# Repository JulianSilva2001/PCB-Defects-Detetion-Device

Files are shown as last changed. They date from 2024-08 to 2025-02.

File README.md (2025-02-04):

# PCB Defects Detection Device

This repository contains the code and resources for a PCB defects detection device. The project utilizes computer vision techniques and machine learning models to identify and classify defects in printed circuit boards (PCBs). 

## Overview

The PCB defects detection device is designed to automate the inspection process, ensuring high-quality standards in PCB manufacturing. The device employs a camera to capture images of PCBs and uses a trained model to detect various types of defects.

## Features

- *Defect Detection:* Identifies multiple PCB defects using a trained YOLOv8 model.
- *Component Placement Verification:* Compares PCB images to detect misaligned or missing components.

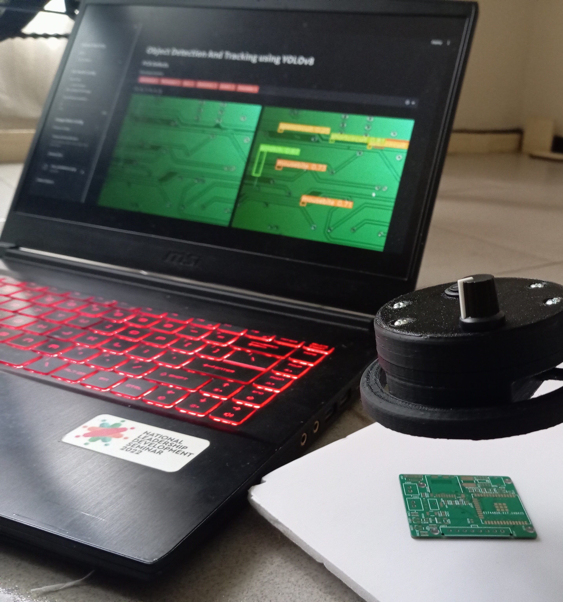
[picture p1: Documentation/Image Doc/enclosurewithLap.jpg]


- **Computer Vision**: The project uses computer vision to process and analyze images of PCBs. This involves techniques such as image enhancement, feature matching, image transformation,  feature extraction, and object detection.
- **Model Training**: A machine learning model is trained on a dataset of PCB images with labeled defects. The model learns to identify and classify defects based on patterns in the images.
- **PCB Schematic and Design**: The repository includes the PCB schematic and design files, providing a comprehensive guide to the hardware setup.
- **Enclosure Design**: Design files for the device enclosure are also included, ensuring a complete package for building the physical device.
- **Web App**: The code for the web application used to interact with the device is also available, allowing for real-time monitoring and analysis through a user-friendly interface.

## PCB and Schematic Design

### 🔩 Component Selection
The PCB inspection device consists of the following key modules:
1. **Microcontroller:** ESP-WROOM-32 (ESP32)
2. **Camera:** OV2460
3. **Lighting System:** High-brightness LED strip
4. **Power Supply:** Micro USB-powered regulated system

### 🔌 Microcontroller: ESP-WROOM-32
The ESP32S is chosen for its:
- **WiFi and Bluetooth Integration:** Enables high-speed image transmission (~6 Mbps).
- **Processing Power:** Dual-core Tensilica LX6 (240 MHz) for efficient image processing.
- **Memory:** 520 KB SRAM to support high-performance operations.

### 📷 Camera: OV5640
- **Resolution:** 5MP sensor 
- **Optical Features:** Low light sensitivity and high dynamic range for accurate PCB inspection.
- **Digital Video Port (DVP) Interface:** Ensures seamless integration with ESP32.
- **Power Requirements:** 2.8V core operation, 1.2V I/O.

### 🔋 Power Supply
- **Voltage Regulation:** Converts 5V USB input to required voltages.
- **Stable Power:** Voltage regulators ensure consistent performance.
- **Convenience:** USB-powered for easy deployment.

### 💡 Lighting System
- **LED Strip:** Provides uniform illumination for defect detection.
- **Adjustable Intensity:** Controlled via a potentiometer for adaptable lighting conditions.
- **Enhanced Versatility:** Ensures accurate inspection across diverse environments.

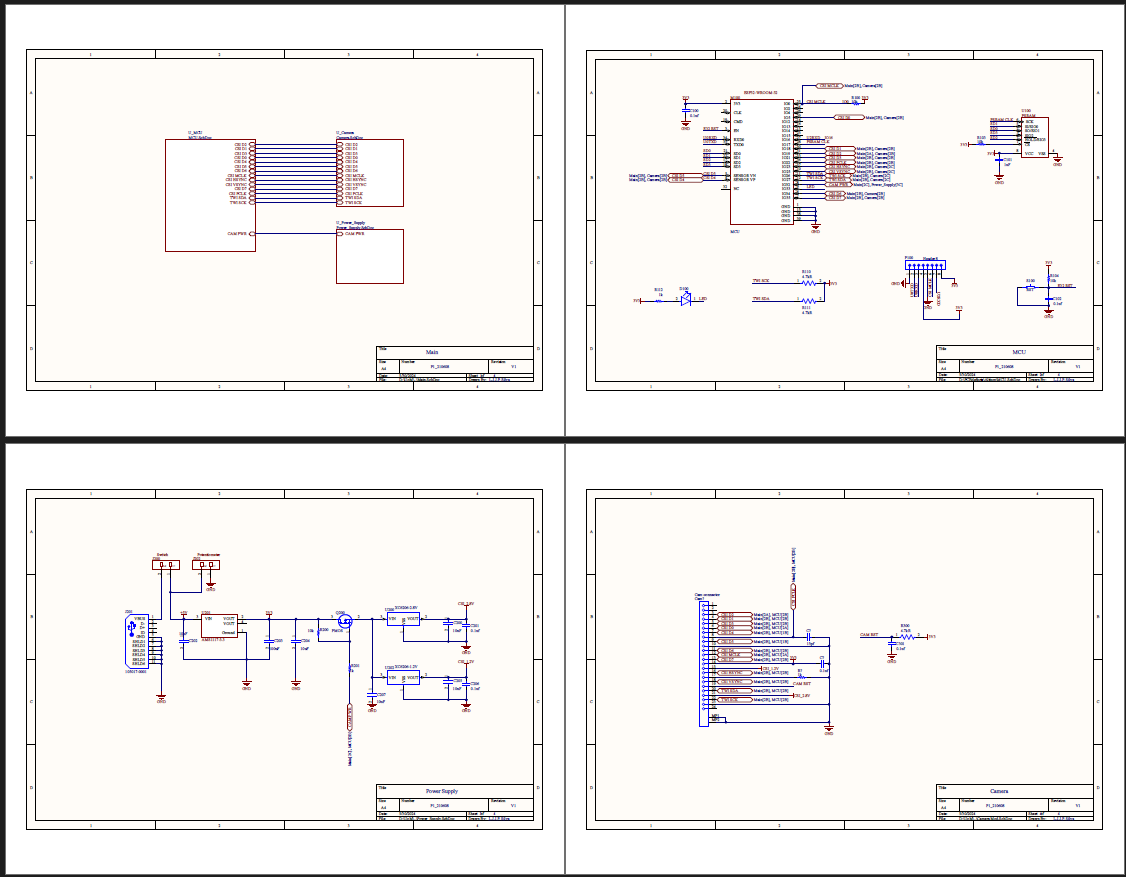
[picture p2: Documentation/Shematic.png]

*Figure 1: Schematic Diagram*

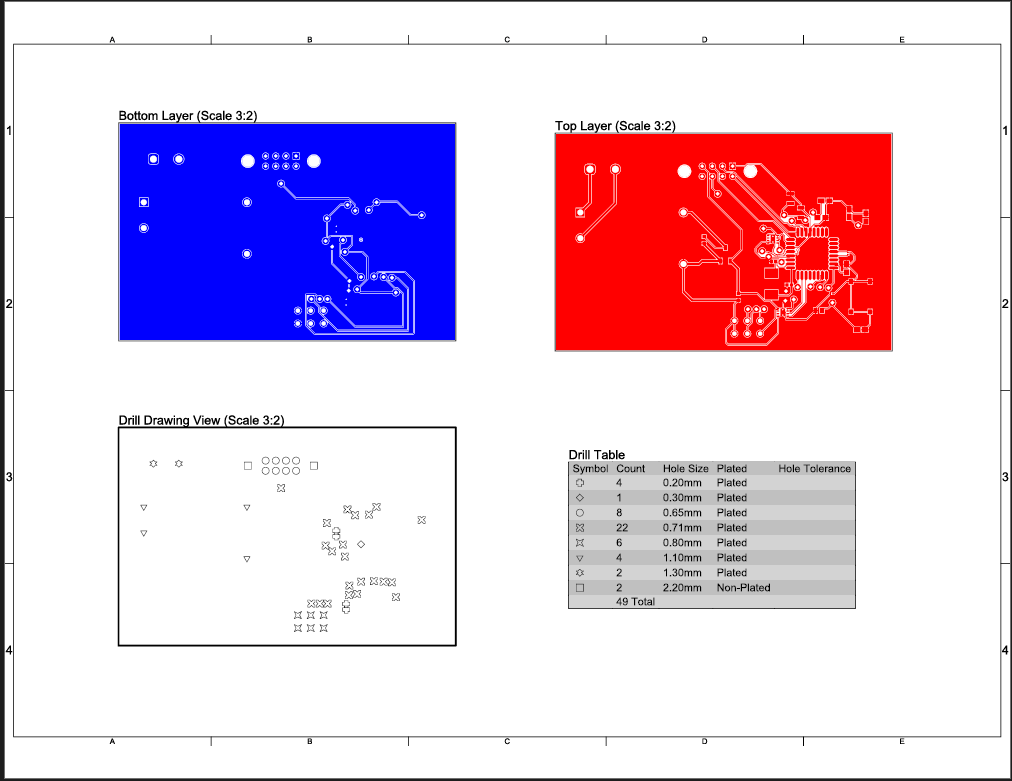
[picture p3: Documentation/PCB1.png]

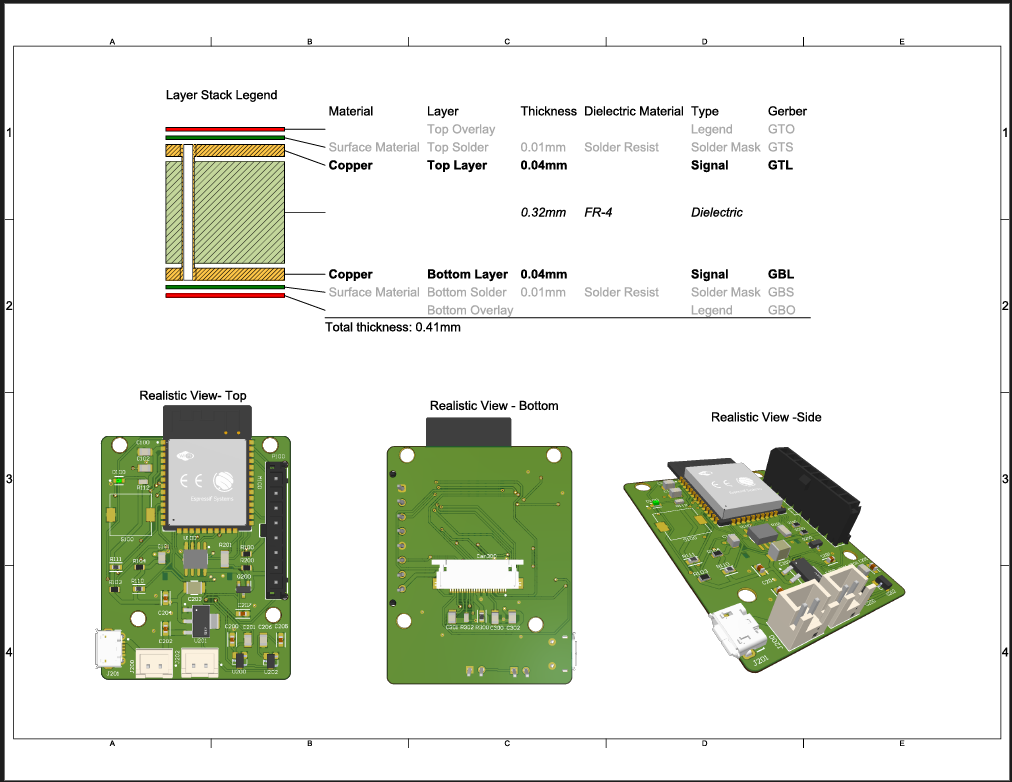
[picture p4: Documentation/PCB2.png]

*Figure 2: PCB Design*

## Enclosure Design 

### 🏗 Key Considerations
The enclosure was designed to optimize functionality, ease of use, and performance:

1. **Mounting for Camera and PCB**
   - Dedicated mounting points secure the camera and PCB for stable inspection.
   
2. **Acrylic Flat Surface**
   - Provides a clear, stable platform for precise PCB inspection.

3. **Adjustable Camera Height**
   - An aluminum bar allows users to set the optimal distance for capturing detailed images.

4. **Ring of Light**
   - Ensures uniform illumination, eliminating shadows for accurate defect detection.

5. **On/Off Button**
   - Controls the power supply, enhancing convenience and safety.

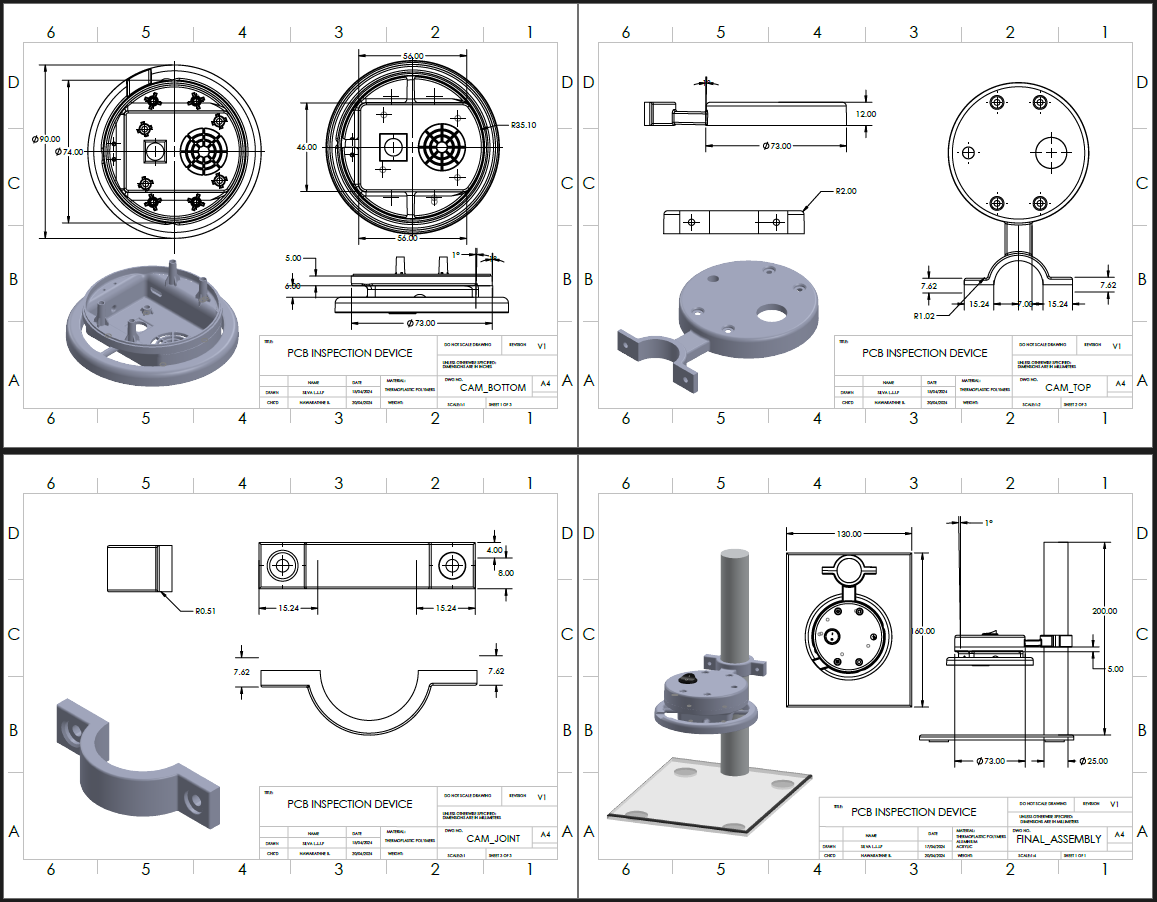
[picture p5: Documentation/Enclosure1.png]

*Figure 3: Enclosure V1*

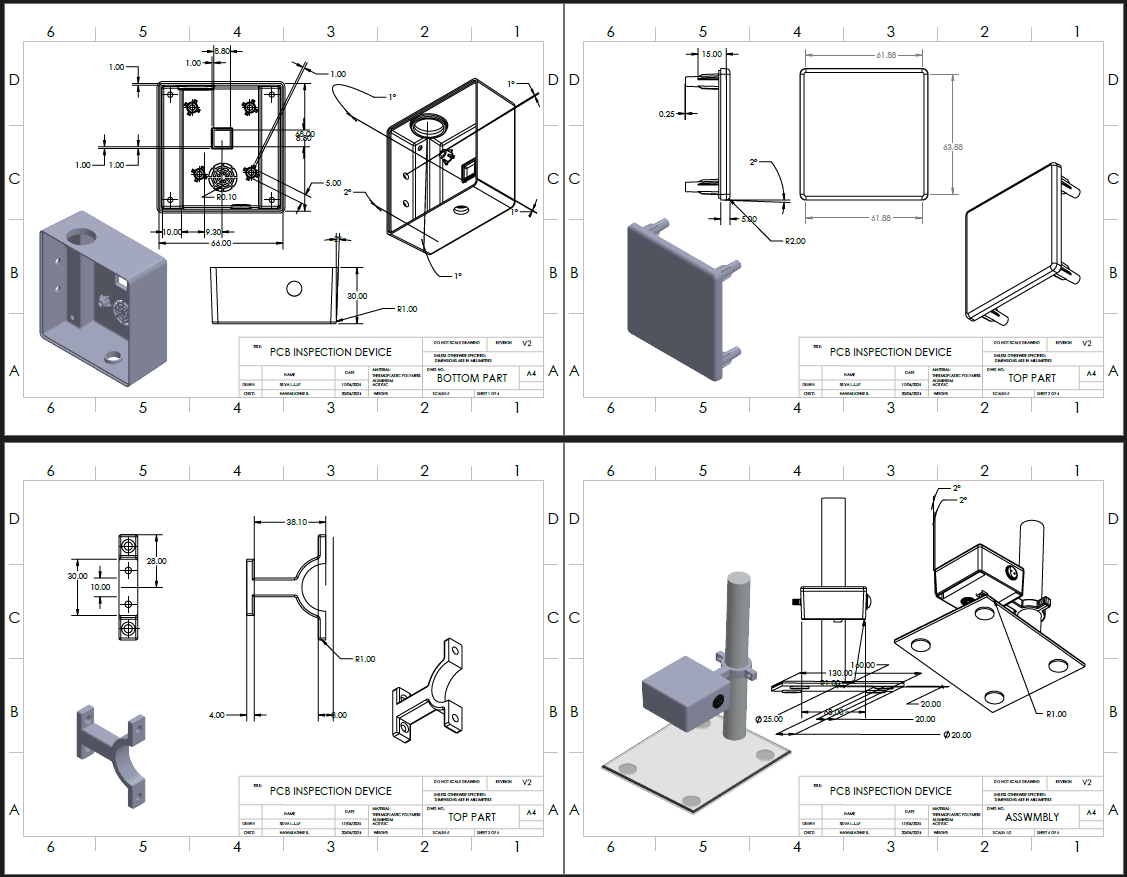
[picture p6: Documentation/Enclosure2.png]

*Figure 4: Enclosure V2*

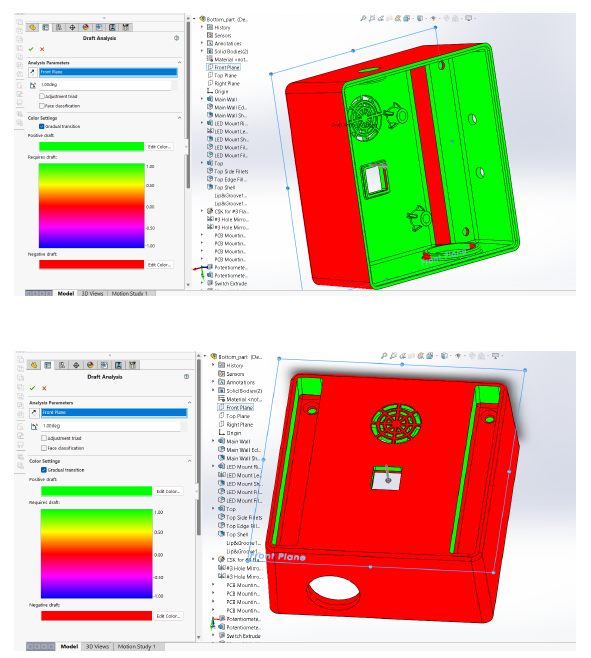
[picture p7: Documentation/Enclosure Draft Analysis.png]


*Figure 5: Draft Analysis*

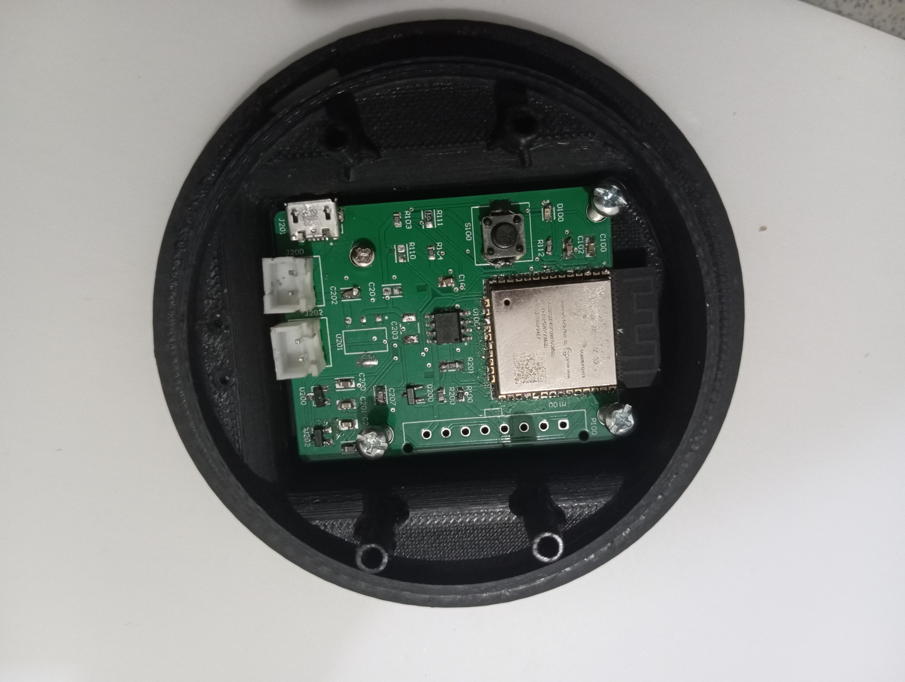
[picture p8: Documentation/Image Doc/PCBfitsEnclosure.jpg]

*Figure 6: How the PCB fits the enclosure*

## 🌐 Building the Web Application

### 📂 Application Structure
The web app offers real-time PCB defect detection through a live camera feed or image uploads.

### 🏠 Home Page
Displays a **welcome message** and describes the types of defects detected:
- Missing Hole
- Mouse Bite
- Open Circuit
- Short Circuit
- Spur
- Spurious Copper

Users can choose between **Live Inspection** or **Upload Images**.

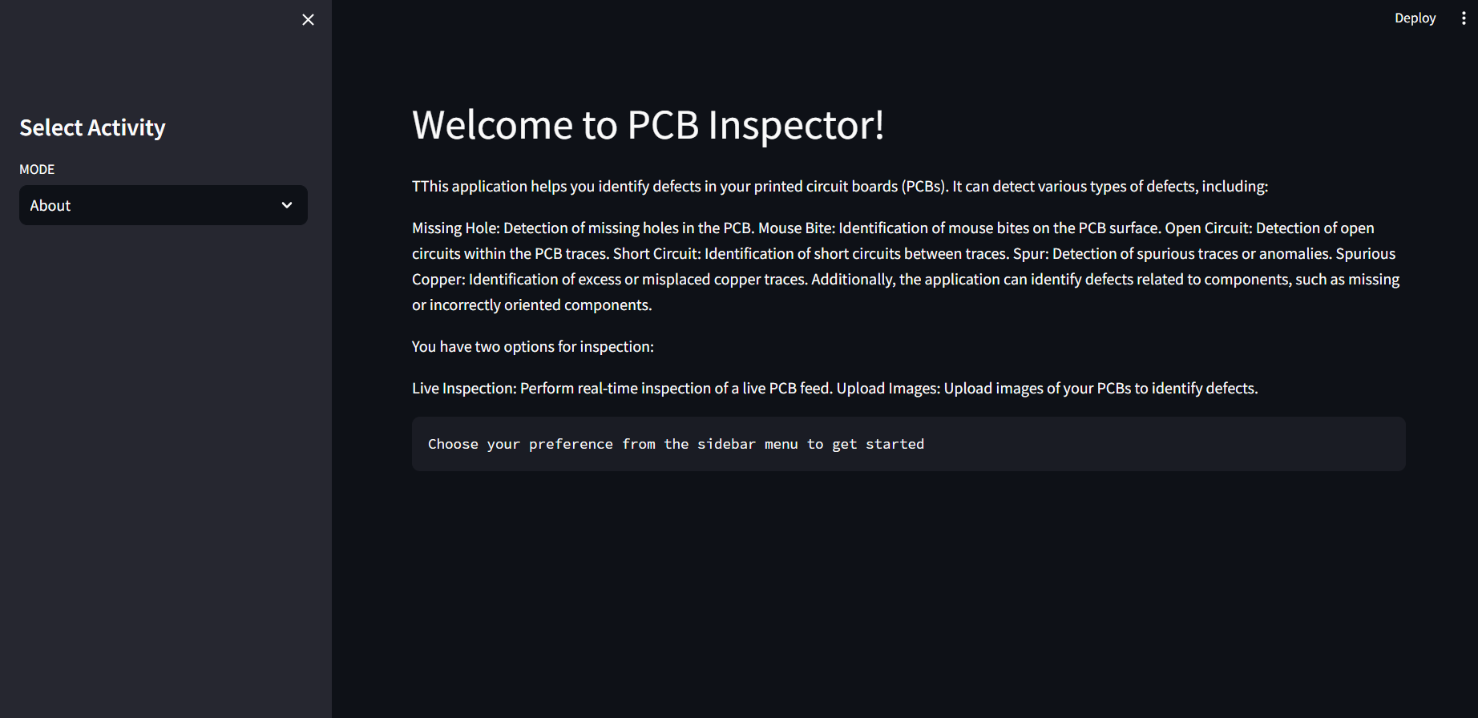
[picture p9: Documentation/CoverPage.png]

*Figure 7: Cover Page*

### 📑 Sidebar Menu
Provides navigation options:
- **About**
- **PCB Defects**
- **Component Defects**

### 🖼 PCB Defects Page
#### ⚙ Model Configuration
Users can:
- Select **Live Camera** or **Upload PCB Image**.
- Adjust model confidence using a slider.

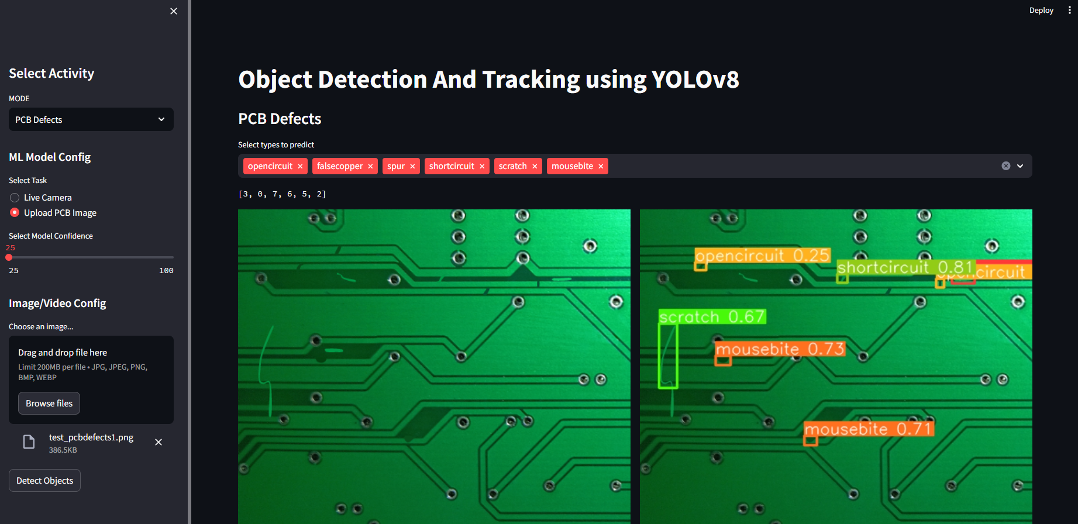
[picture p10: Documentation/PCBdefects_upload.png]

*Figure 8: PCB defects Detection Page* 

#### 🎥 Live Camera Mode
- Captures real-time images.
- Detects defects using the YOLO model.
- Highlights defects on the processed image.

#### 📤 Upload PCB Image Mode
- Users upload PCB images in various formats.
- The app processes and highlights detected defects.

### 🔩 Component Defects Page
Similar to PCB defects detection, but focuses on **component placement**.

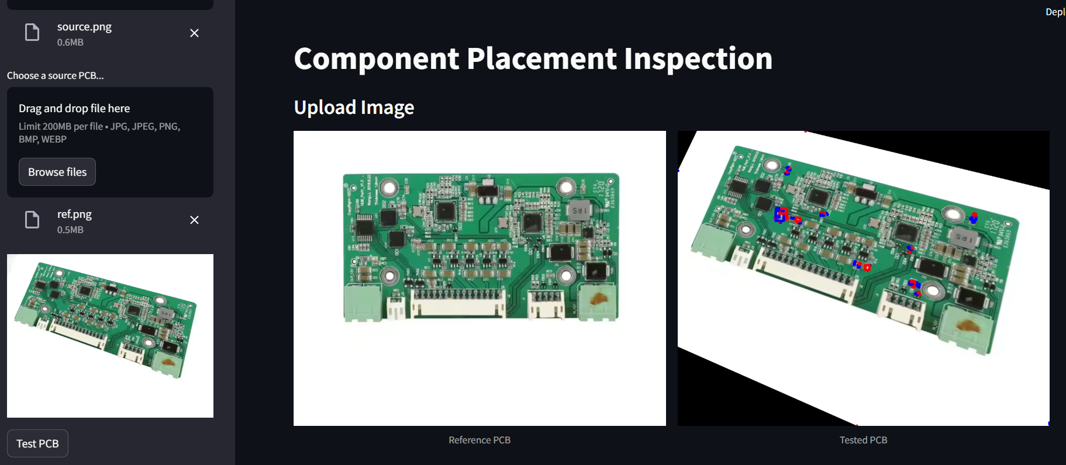
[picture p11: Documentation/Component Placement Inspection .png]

*Figure 8: Component Placement Inspection Page* 

#### 🎥 Live Camera Mode
- Captures a reference image.
- Compares it with live images to detect misalignments.

#### 📤 Upload PCB Image Mode
- Users upload a **reference** and **source image**.
- The app highlights component defects based on differences.

## Getting Started

1. **Clone the Repository**: 
    ```bash
    git clone https://github.com/yourusername/pcb-defects-detection-device.git
    ```

2. **Running the Device**: Follow the setup instructions in the documentation to assemble the hardware and run the device.

🤝 Contributing

Contributions are welcome! Feel free to submit issues or pull requests.

## Documentation

Detailed documentation, including setup instructions and usage guidelines, can be found in the [project document](https://github.com/JulianSilva2001/PCB-Defects-Detetion-Device/blob/main/Documentation/PCB_Defects_Detection_Documentation%20(7).pdf).

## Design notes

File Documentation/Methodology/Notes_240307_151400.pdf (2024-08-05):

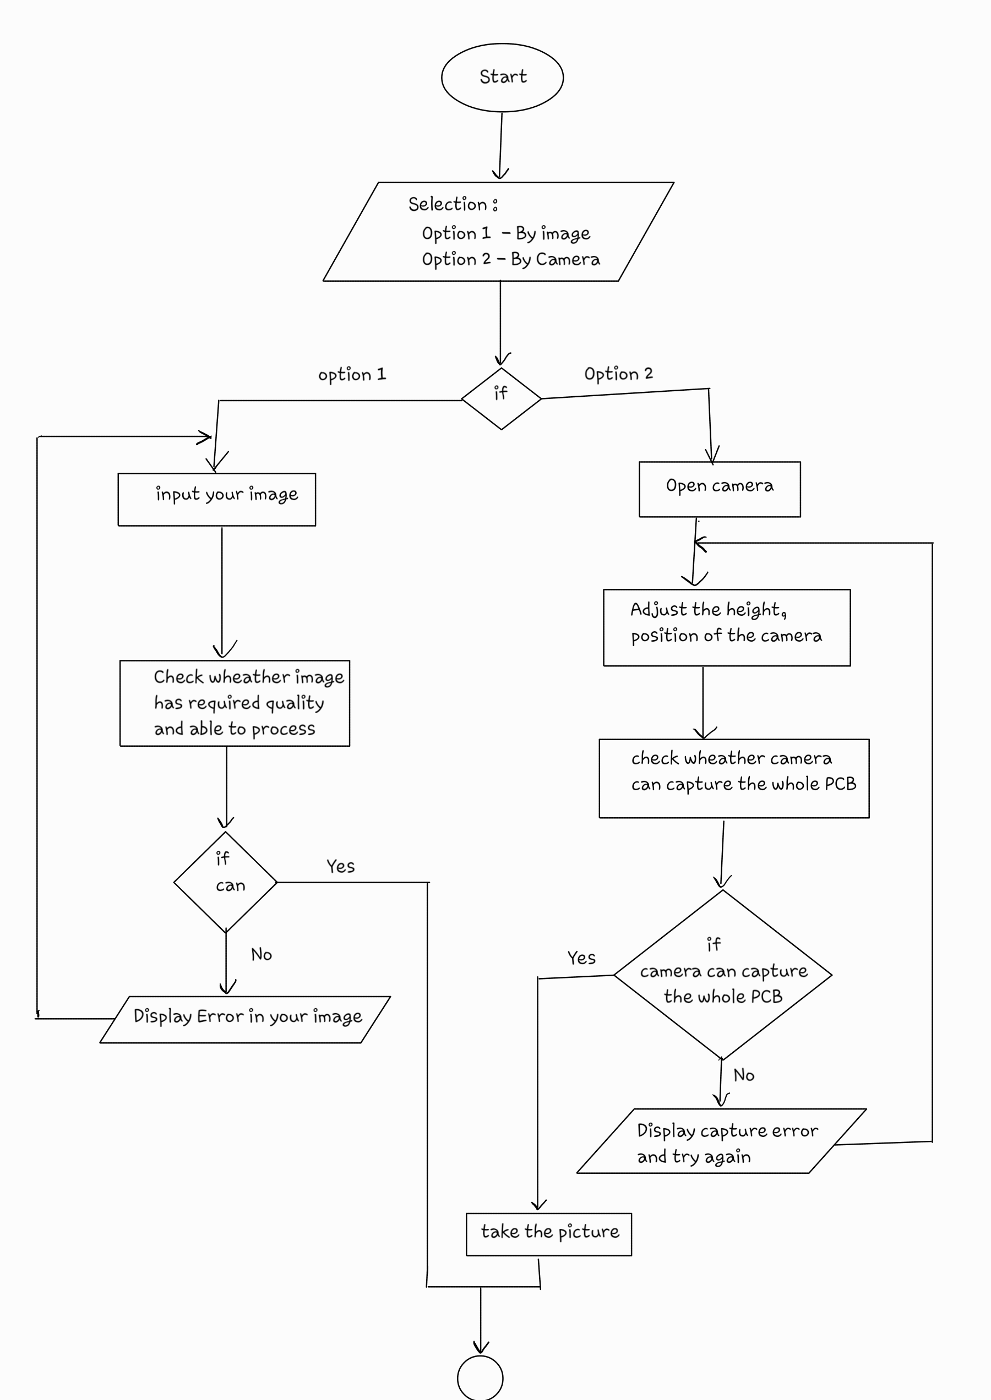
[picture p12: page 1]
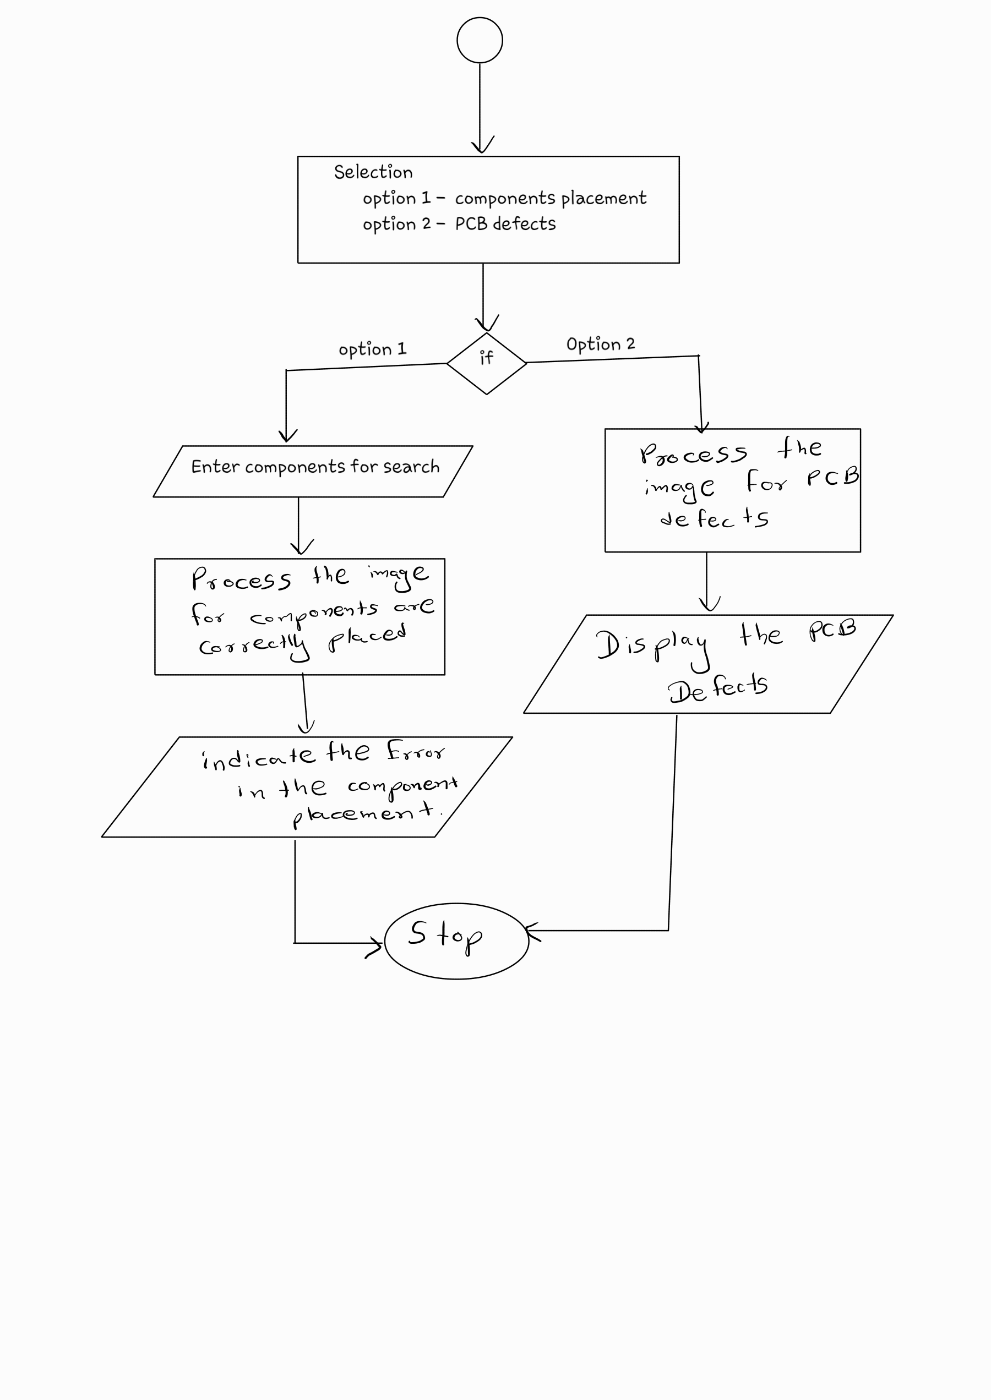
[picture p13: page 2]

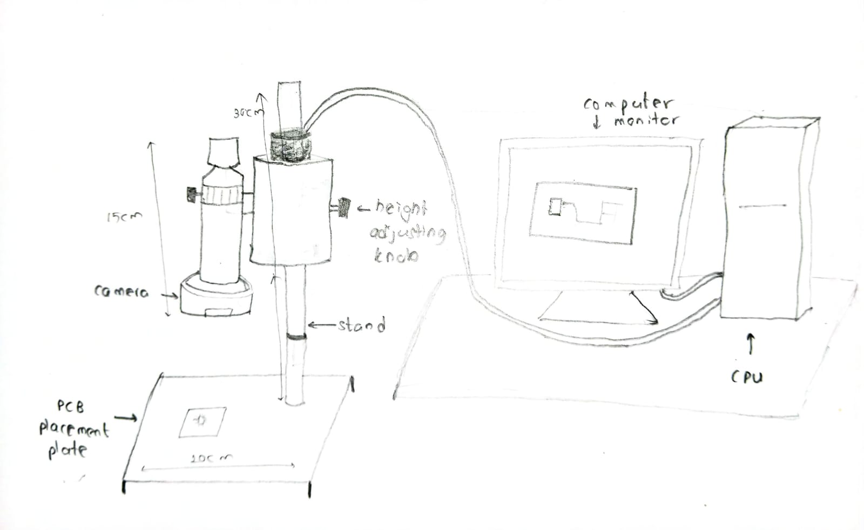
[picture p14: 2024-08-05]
Documentation/Methodology/Conceptual Design/CD_Comp.jpg

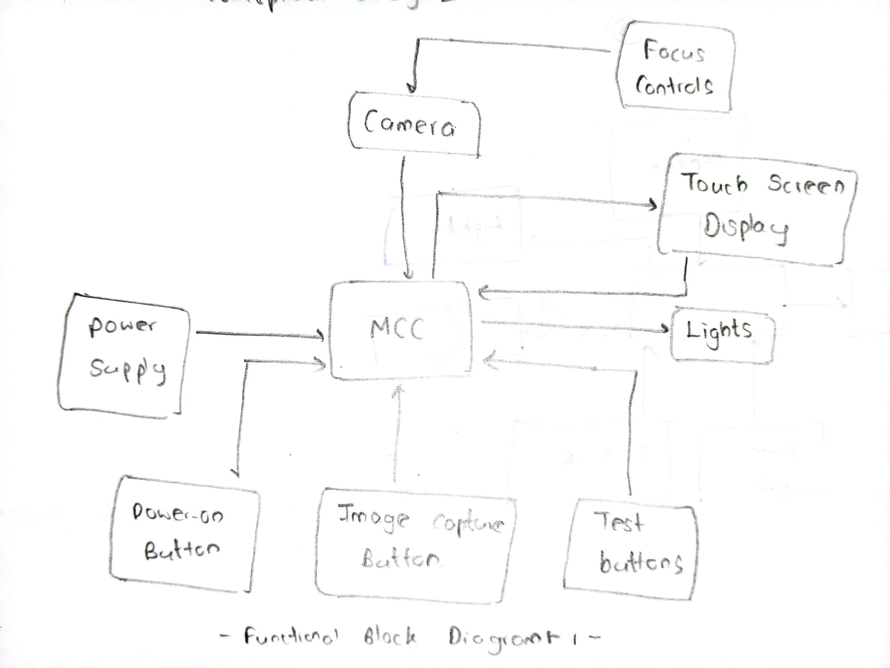
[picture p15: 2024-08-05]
Documentation/Methodology/Conceptual Design/FD_display.jpg

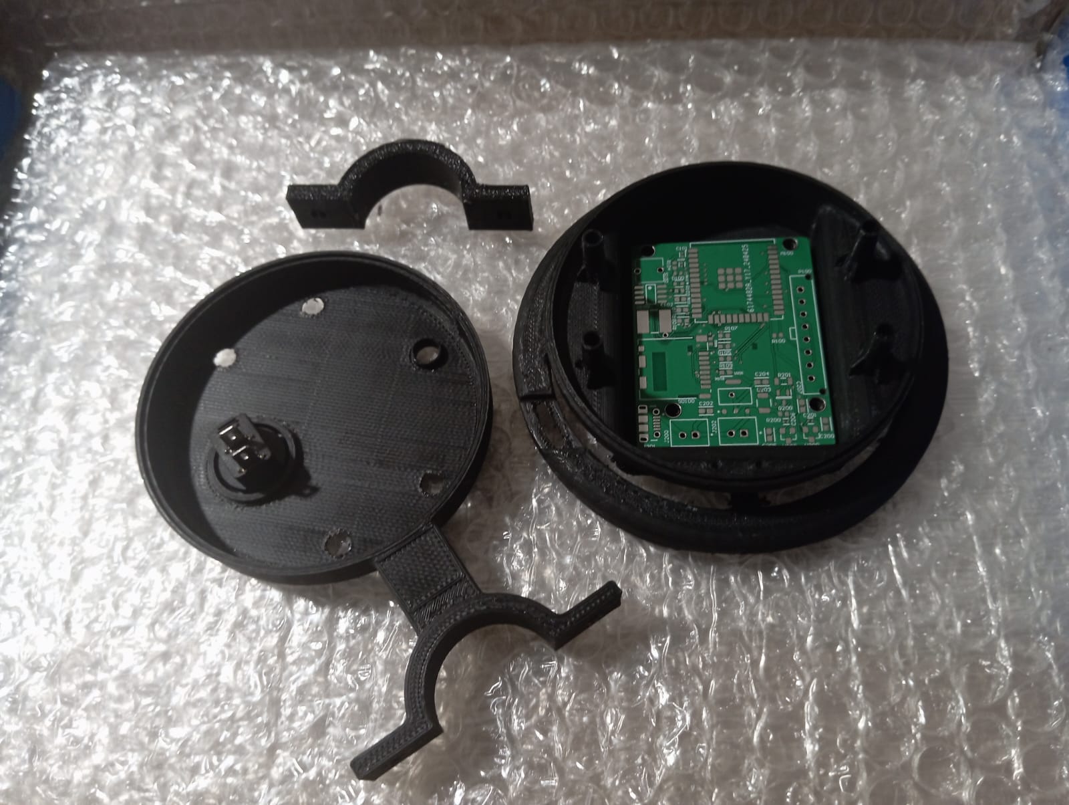
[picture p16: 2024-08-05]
Documentation/Conceptual Design/Enclosure/Enclosure Design A3.jpg

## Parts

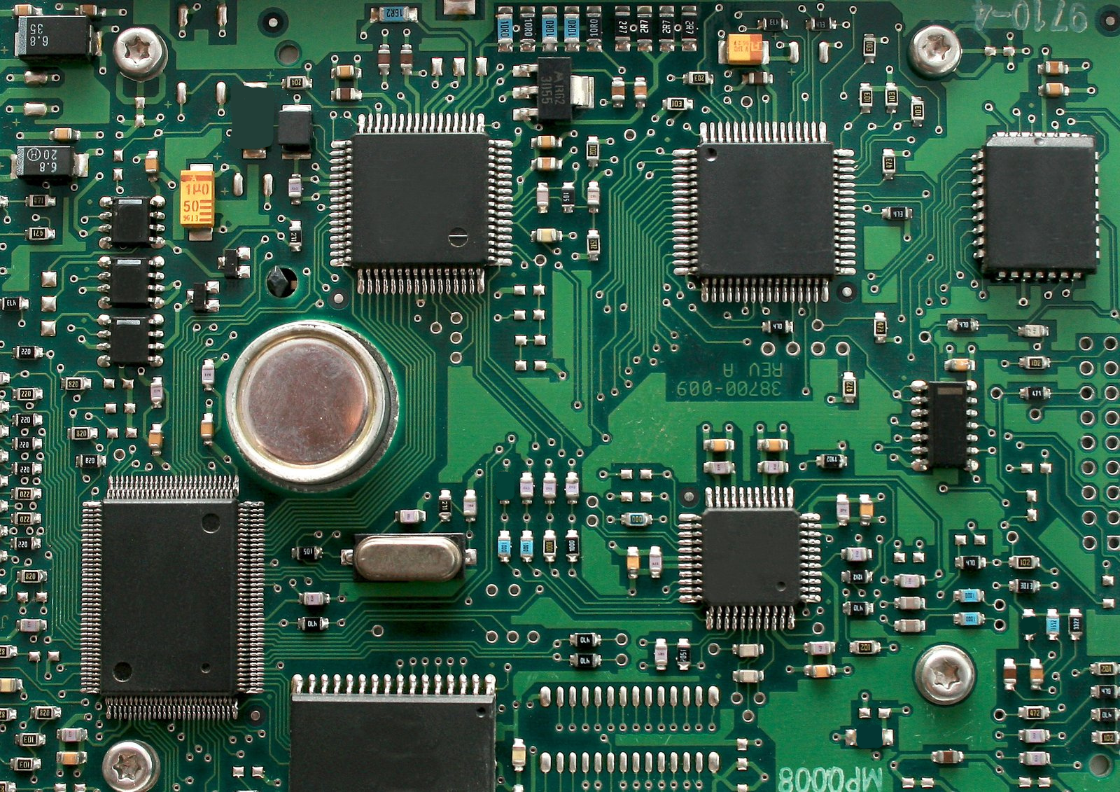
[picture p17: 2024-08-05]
code/Test Images/Component Deffects/PCB_Ctest1_D.png

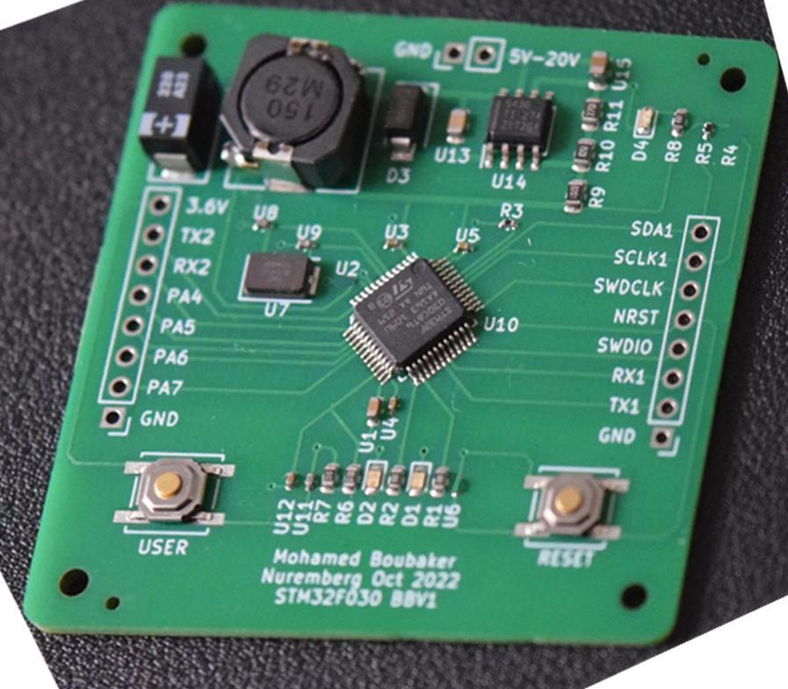
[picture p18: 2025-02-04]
code/Test Images/Component Deffects/anamoly_2/warped.png

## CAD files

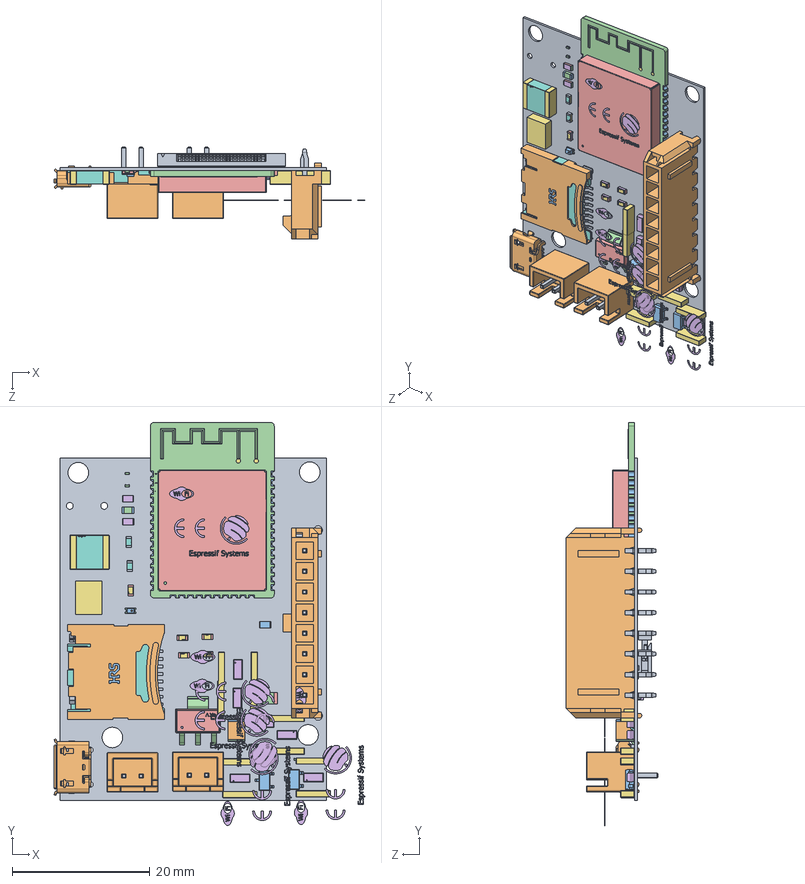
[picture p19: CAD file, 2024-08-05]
Altium/PCB_F.step.SLDASM
45.2 x 58.6 x 13.3 mm
1.step
2.step
3.step
4.step
Lite-On Logo Adjustable.step
5.step
6.step
1-1.step x 2
B2B-XH-A.step x 2
JST Logo adjustable.step x 2
Mid_Body.step x 2
Mark.step x 2
1-2.step x 3
2-3.step x 3
3-4.step x 3
Panasonic Logo.step x 3
Extruded.step x 2
Extruded-5.step
Pieza60.step x 5
Pieza63.step x 5
Pieza64.step x 5
Pieza65.step x 5
Mid_Body-7.step x 2
Mark-8.step x 2
Cap_Murata_GRM155R71C104KA88D_eec.step x 6
Extruded-9.step
Extruded-10.step x 2
Terminals.step x 6
Center.step
Murata.step
6605298272.step x 2
1-12.step
Notch 2.step
Extruded-13.step
DM3CS-SF.step
Pieza12.step
Pieza13.step
Pieza14.step
Extruded-14.step
Extruded-15.step x 2
Body.step x 6
PinsArrayL.step
FilletPinR.step
6620xx11122_PIN.step x 8
66200811122-16.step
2-18.step
3-19.step
ESP32-WROOM-32D.step
Logo.step x 6
10.step
11.step
Cap_Murata_GRM32ER60J107ME20L_eec.step
Cap_Murata_GRM32ER60J107ME20L_eec-20.step
Cap_Murata_GRM32ER60J107ME20L_eec-21.step

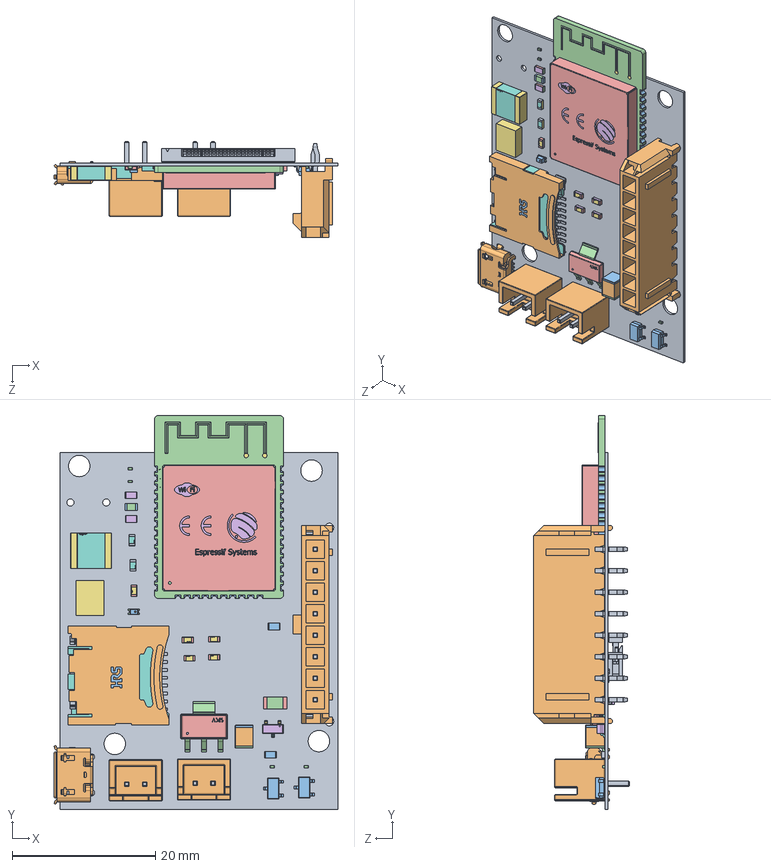
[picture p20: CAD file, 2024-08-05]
Altium/PCB1.step.SLDASM
39.6 x 54.9 x 13.3 mm
1.step
2.step
3.step
4.step
Lite-On Logo Adjustable.step
5.step
6.step
1-1.step x 2
B2B-XH-A.step x 2
JST Logo adjustable.step x 2
Mid_Body.step x 2
Mark.step x 2
1-2.step x 3
2-3.step x 3
3-4.step x 3
Panasonic Logo.step x 3
Extruded.step x 2
Extruded-5.step
Pieza60.step x 5
Pieza63.step x 5
Pieza64.step x 5
Pieza65.step x 5
Mid_Body-7.step x 2
Mark-8.step x 2
Cap_Murata_GRM155R71C104KA88D_eec.step x 6
Extruded-9.step
Extruded-10.step x 2
Terminals.step
Center.step
Murata.step
6606193888.step x 2
1-12.step
Notch 2.step
Extruded-13.step
DM3CS-SF.step
Pieza12.step
Pieza13.step
Pieza14.step
Extruded-14.step
Extruded-15.step x 2
Body.step
PinsArrayL.step
FilletPinR.step
6620xx11122_PIN.step x 8
66200811122-16.step
2-18.step
3-19.step
ESP32-WROOM-32D.step
Logo.step
10.step
11.step
Cap_Murata_GRM32ER60J107ME20L_eec.step
Cap_Murata_GRM32ER60J107ME20L_eec-20.step
Cap_Murata_GRM32ER60J107ME20L_eec-21.step

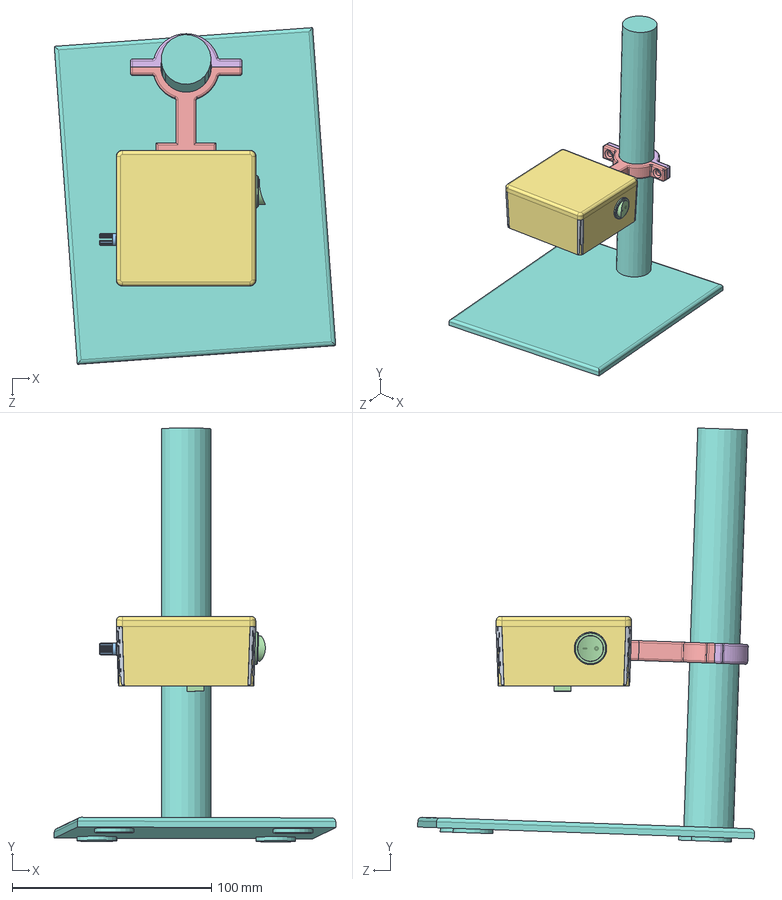
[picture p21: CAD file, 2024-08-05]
Solidworks V2/AssemV2.SLDASM
141.2 x 207.7 x 169.0 mm
Bottom_part
PCB1.step
POT10K.step
Button v5.step
Joint
Joint_part
Bottom
base
User Library-LI-OV5640-MIPI-AF_Designator1
User Library-LI-OV5640-MIPI-AF_942681200
User Library-LI-OV5640-MIPI-AF_942681064
User Library-LI-OV5640-MIPI-AF_942680928
User Library-LI-OV5640-MIPI-AF_942680792
User Library-LI-OV5640-MIPI-AF_942680656
User Library-LI-OV5640-MIPI-AF_942676304

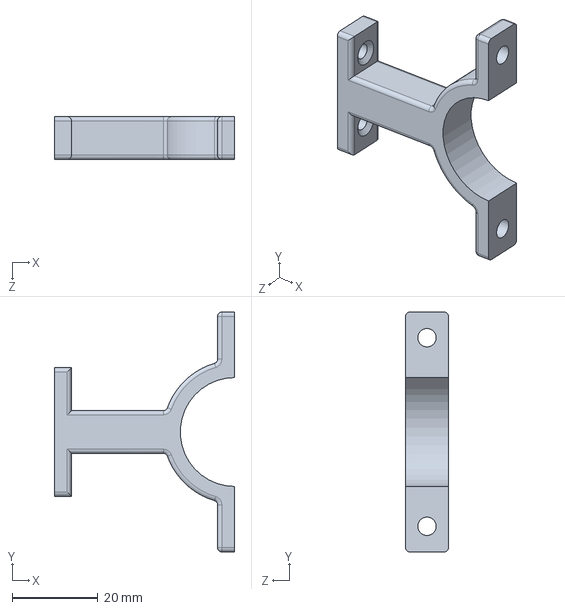
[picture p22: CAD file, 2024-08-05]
Solidworks V2/Joint.SLDPRT
42.1 x 56.0 x 10.0 mm

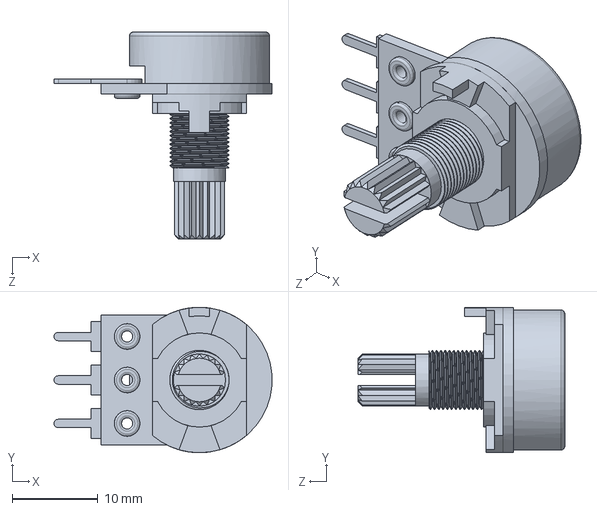
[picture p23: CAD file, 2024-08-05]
Solidworks V2/PCB/POT10K.step.SLDPRT
25.5 x 17.0 x 24.2 mm

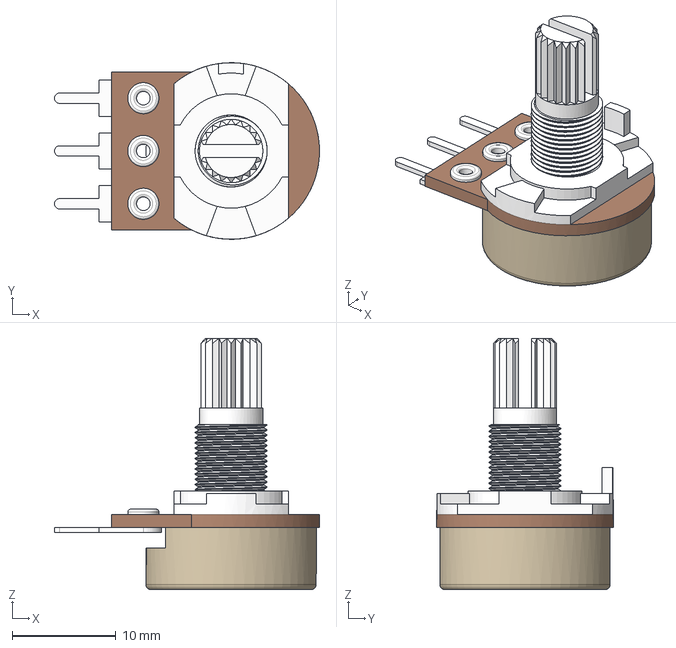
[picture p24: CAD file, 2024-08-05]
Solidworks V2/PCB/potentiometer-10k-2.snapshot.2 (1)/POT10K.step
25.5 x 17.0 x 24.2 mm

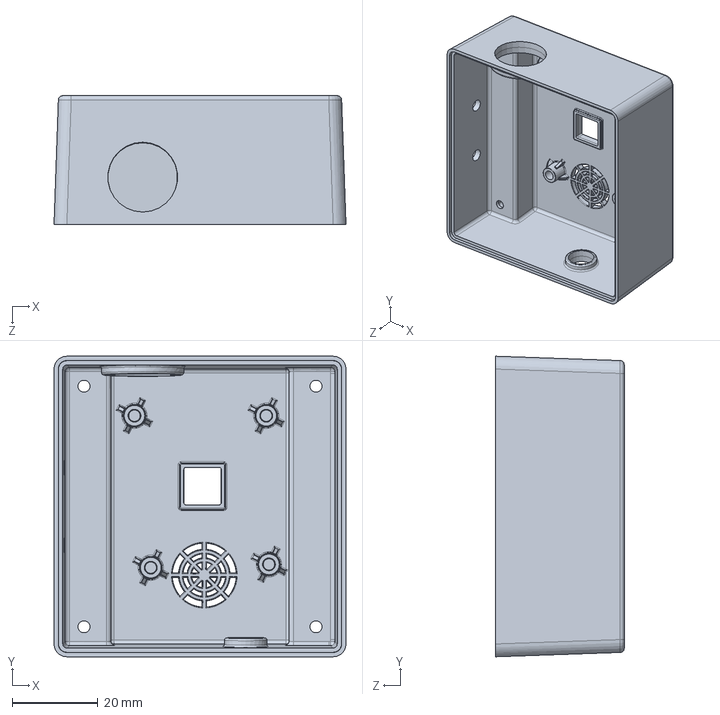
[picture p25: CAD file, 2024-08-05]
Solidworks V2/Bottom_part.SLDPRT
68.1 x 70.1 x 30.0 mm

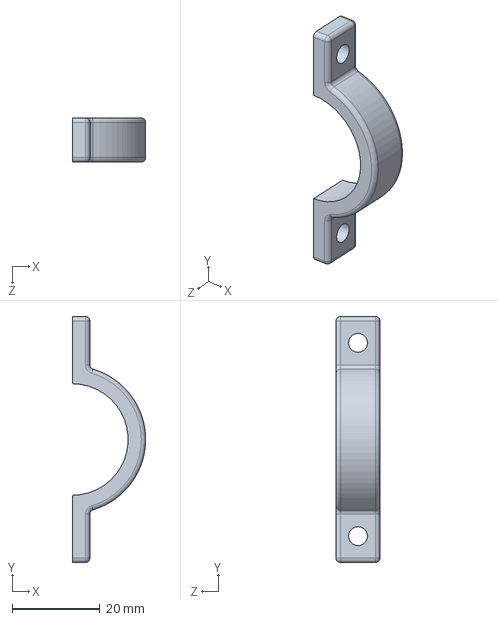
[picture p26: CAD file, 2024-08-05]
Solidworks V2/Joint_part.SLDPRT
16.7 x 56.0 x 10.0 mm

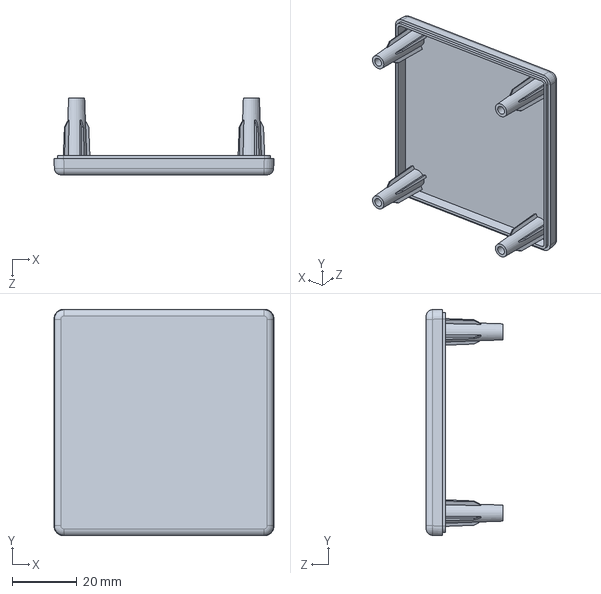
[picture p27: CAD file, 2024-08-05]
Solidworks V2/Bottom.SLDPRT
68.1 x 70.1 x 23.7 mm

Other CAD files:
Solidworks V2/PCB/potentiometer-10k-2.snapshot.2 (1)/POT10K.f3d
Solidworks V2/PCB/potentiometer-10k-2.snapshot.2 (1)/POT10K.obj

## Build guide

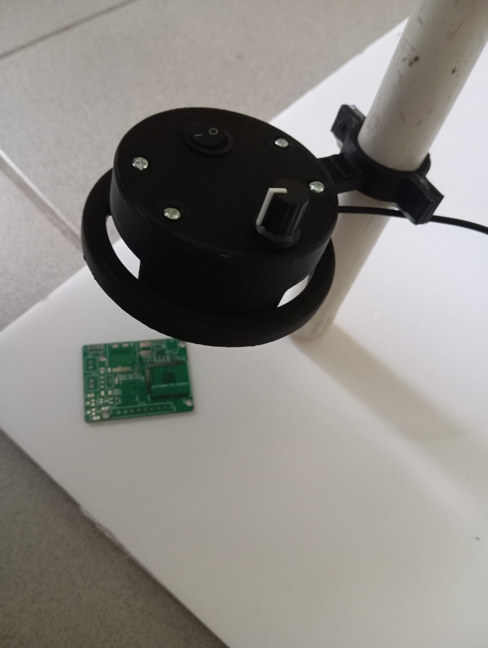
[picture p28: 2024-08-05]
Documentation/Image Doc/AssembledEnclosure2.jpg

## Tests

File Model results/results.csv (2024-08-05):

epoch | train/box_loss | train/cls_loss | train/dfl_loss | metrics/precision(B) | metrics/recall(B) | metrics/mAP50(B) | metrics/mAP50-95(B) | val/box_loss | val/cls_loss | val/dfl_loss | lr/pg0 | lr/pg1 | lr/pg2
1 | 2.5854 | 3.2818 | 1.4706 | 0.55606 | 0.61447 | 0.50088 | 0.19827 | 2.0494 | 7.168 | 1.1111 | 0.00027717 | 0.00027717 | 0.00027717
2 | 2.2103 | 1.6528 | 1.2155 | 0.70733 | 0.64771 | 0.66522 | 0.27632 | 1.9371 | 1.3186 | 1.0629 | 0.00052737 | 0.00052737 | 0.00052737
3 | 2.1476 | 1.5325 | 1.1813 | 0.75465 | 0.73706 | 0.75189 | 0.3144 | 1.9139 | 1.2722 | 1.0606 | 0.00075008 | 0.00075008 | 0.00075008
4 | 2.0644 | 1.4209 | 1.1518 | 0.75439 | 0.73968 | 0.76909 | 0.34063 | 1.8497 | 1.1182 | 1.0348 | 0.0007093 | 0.0007093 | 0.0007093
5 | 2.0046 | 1.3218 | 1.122 | 0.79086 | 0.77871 | 0.80208 | 0.3538 | 1.828 | 1.0678 | 1.0296 | 0.00066807 | 0.00066807 | 0.00066807
6 | 1.9478 | 1.2496 | 1.1023 | 0.81205 | 0.81001 | 0.82711 | 0.37972 | 1.7286 | 0.98288 | 0.99394 | 0.00062683 | 0.00062683 | 0.00062683
7 | 1.8992 | 1.1829 | 1.0803 | 0.82555 | 0.82302 | 0.84485 | 0.39776 | 1.702 | 0.92843 | 0.98793 | 0.0005856 | 0.0005856 | 0.0005856
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

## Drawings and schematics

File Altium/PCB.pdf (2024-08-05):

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
CSI D2
CSI D1
CSI D3
CSI D0
CSI D4
CSI D5
CSI D6
CSI MCLK
CSI HSYNC
CSI VSYNC
CSI D7
CSI PCLK
TWI SDA
TWI SCK

U_Camera
Camera.SchDoc

CAM PWR

U_Power_Supply
Power_Supply.SchDoc

CSI D5

CSI D4

CSI D1

CSI D2

CSI D3

CSI PCLK

CSI HSYNC
CSI VSYNC
CSI D7

CSI D6

CAM PWR

CSI MCLK

CSI D0

TWI SDA
TWI SCK

U_MCU
MCU.SchDoc

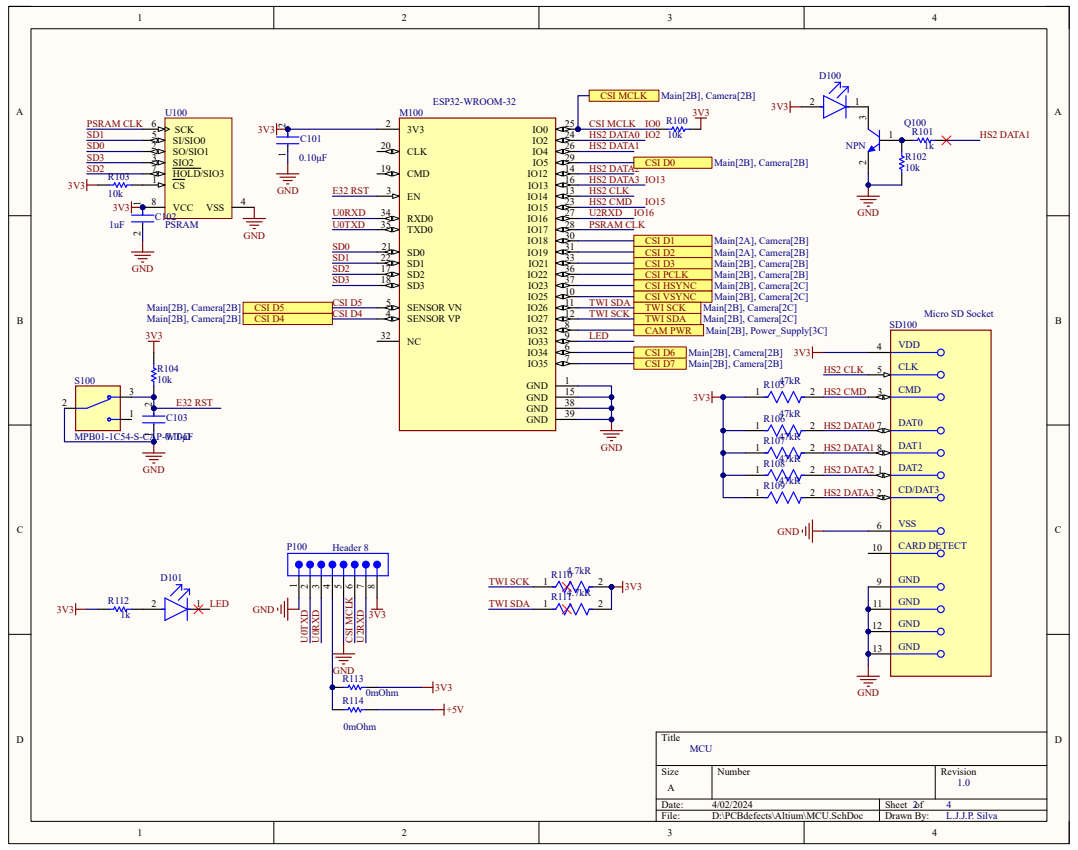
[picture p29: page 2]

# GND⁰¹ ⁰¹ 02 02 03 03 04 04

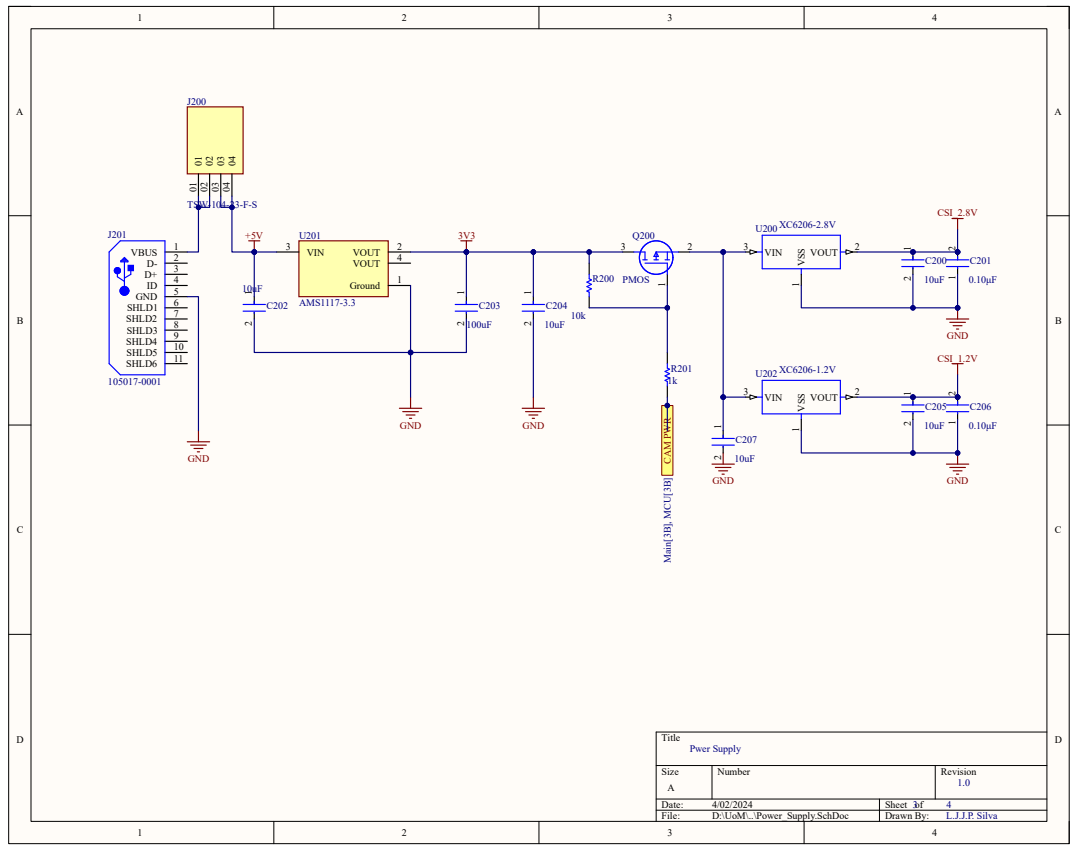
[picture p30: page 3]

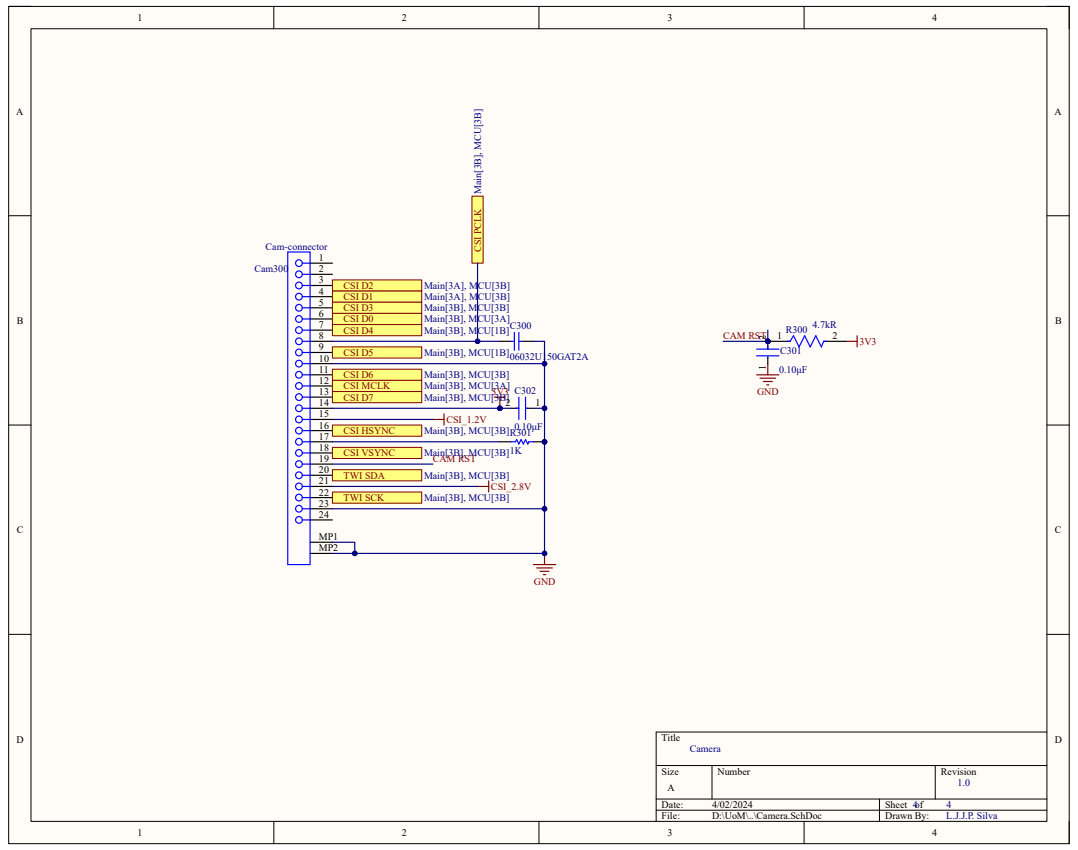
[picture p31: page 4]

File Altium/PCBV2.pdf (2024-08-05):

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
CSI D2
CSI D1
CSI D3
CSI D0
CSI D4
CSI D5
CSI D6
CSI MCLK
CSI HSYNC
CSI VSYNC
CSI D7
CSI PCLK
TWI SDA
TWI SCK

U_Camera
Camera.SchDoc

CAM PWR

U_Power_Supply
Power_Supply.SchDoc

CSI D5

CSI D4

CSI D1

CSI D2

CSI D3

CSI PCLK

CSI HSYNC
CSI VSYNC
CSI D7

CSI D6

CAM PWR

CSI MCLK

CSI D0

TWI SDA
TWI SCK

U_MCU
MCU.SchDoc

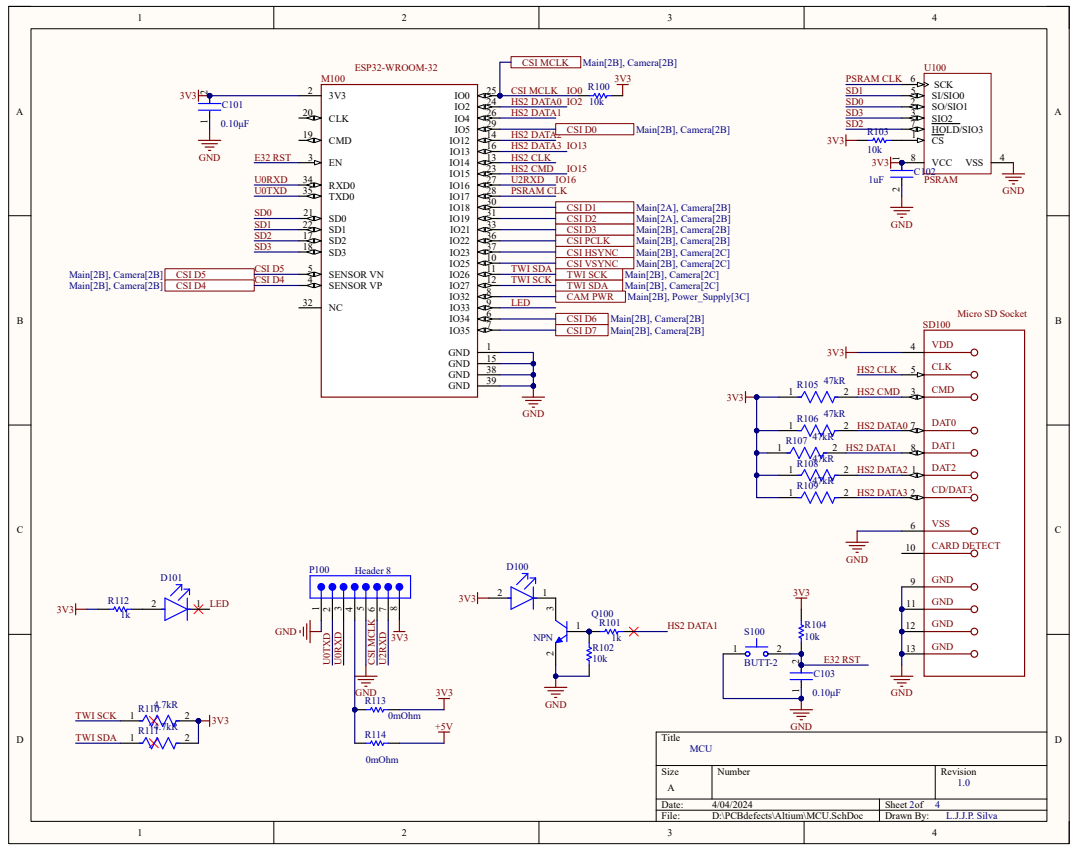
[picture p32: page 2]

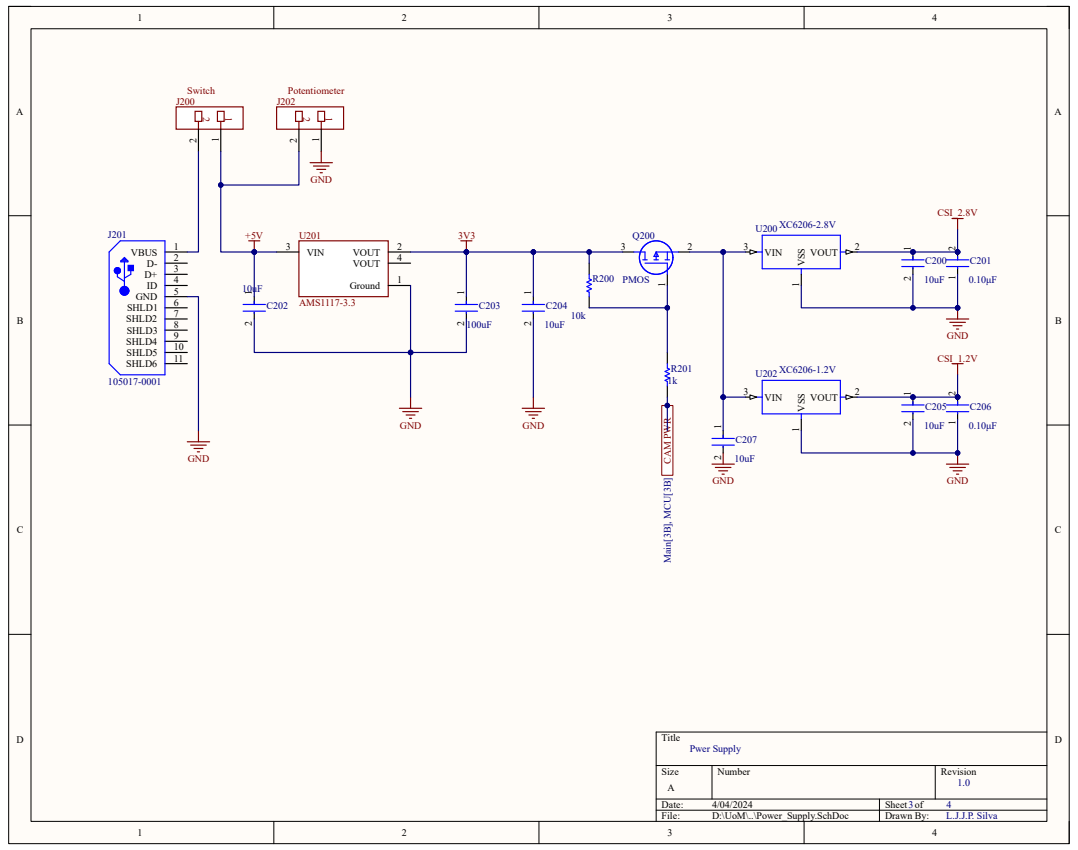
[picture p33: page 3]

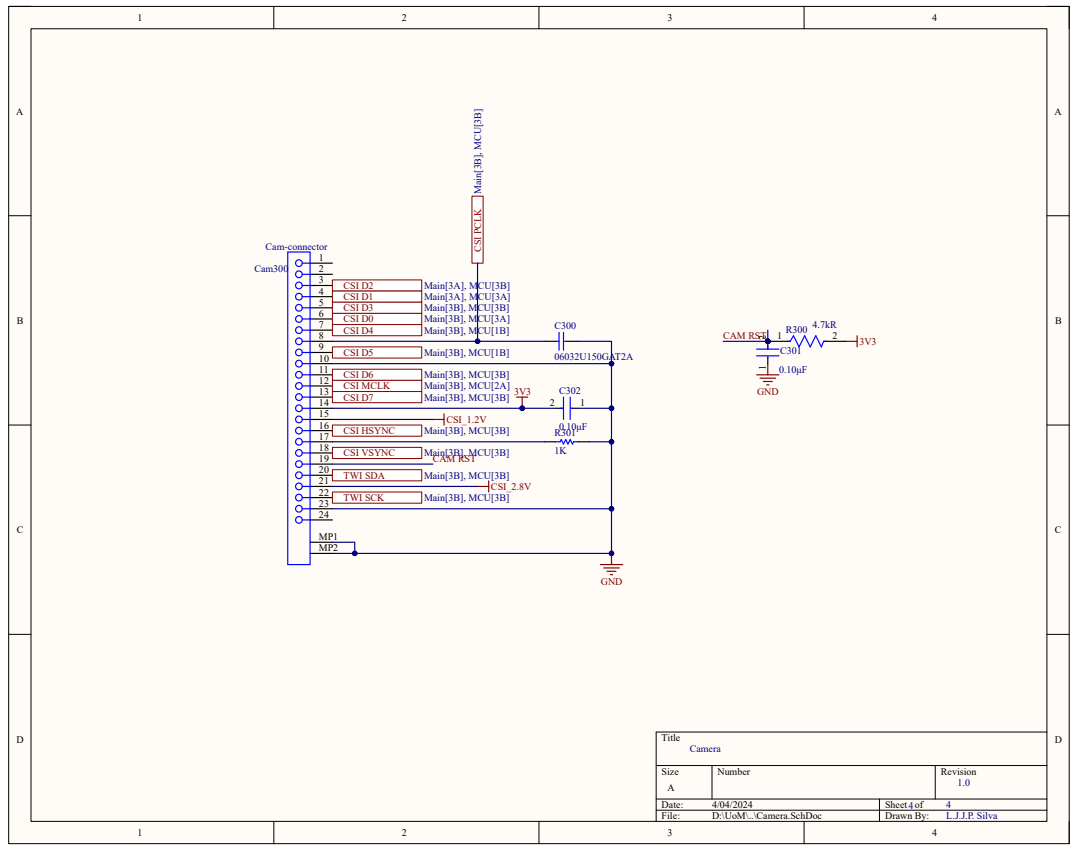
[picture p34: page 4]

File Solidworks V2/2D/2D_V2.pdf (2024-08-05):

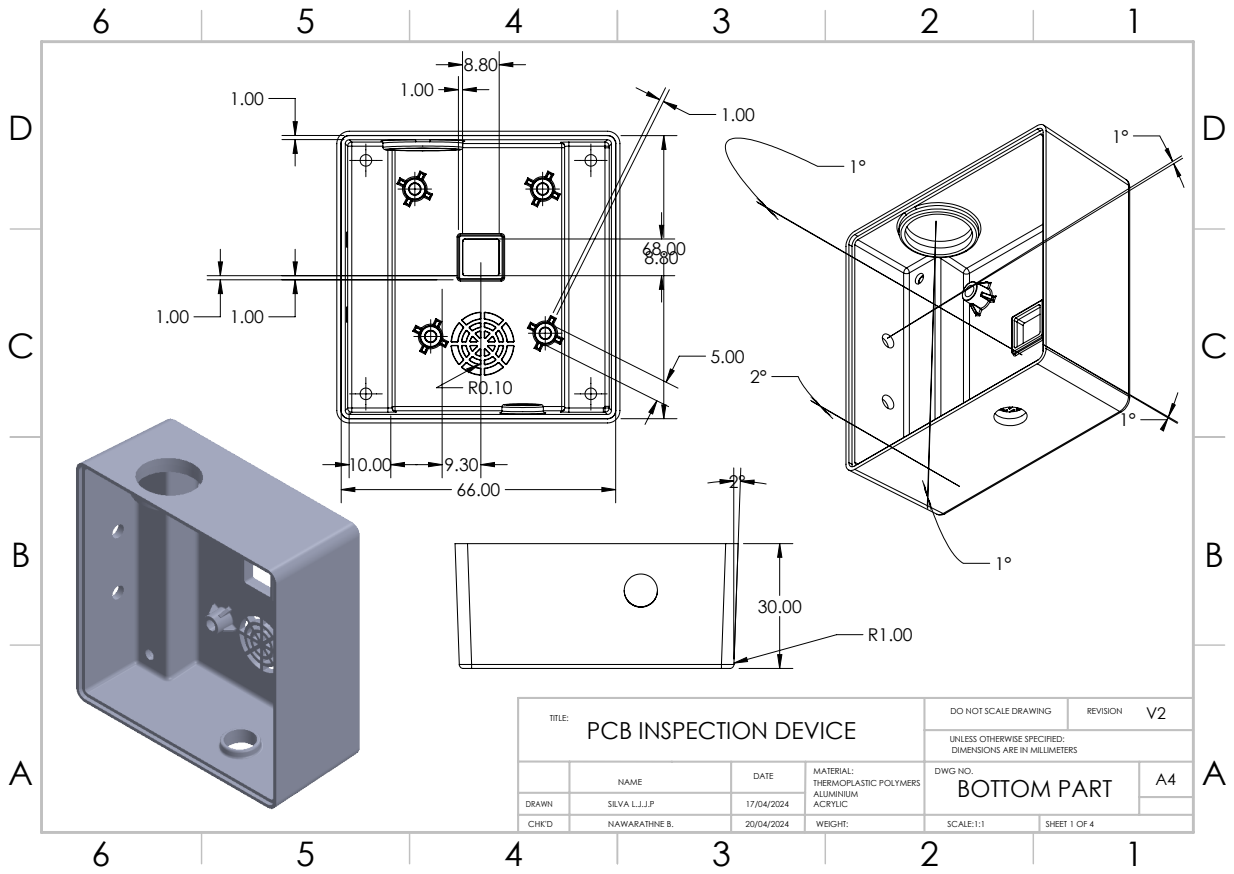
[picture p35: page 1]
DO NOT SCALE DRAWING; REVISION TITLE:

PCB INSPECTION DEVICE

UNLESS OTHERWISE SPECIFIED:
DIMENSIONS ARE IN MILLIMETERS

NAME | DATE | MATERIAL: THERMOPLASTIC POLYMERS ALUMINIUM ACRYLIC | DWG NO. BOTTOM PART SILVA L.J.J.P | A4

DRAWN
CHK'D | NAWARATHNE B. | | WEIGHT: | SCALE:1:1 | SHEET 1 OF 4

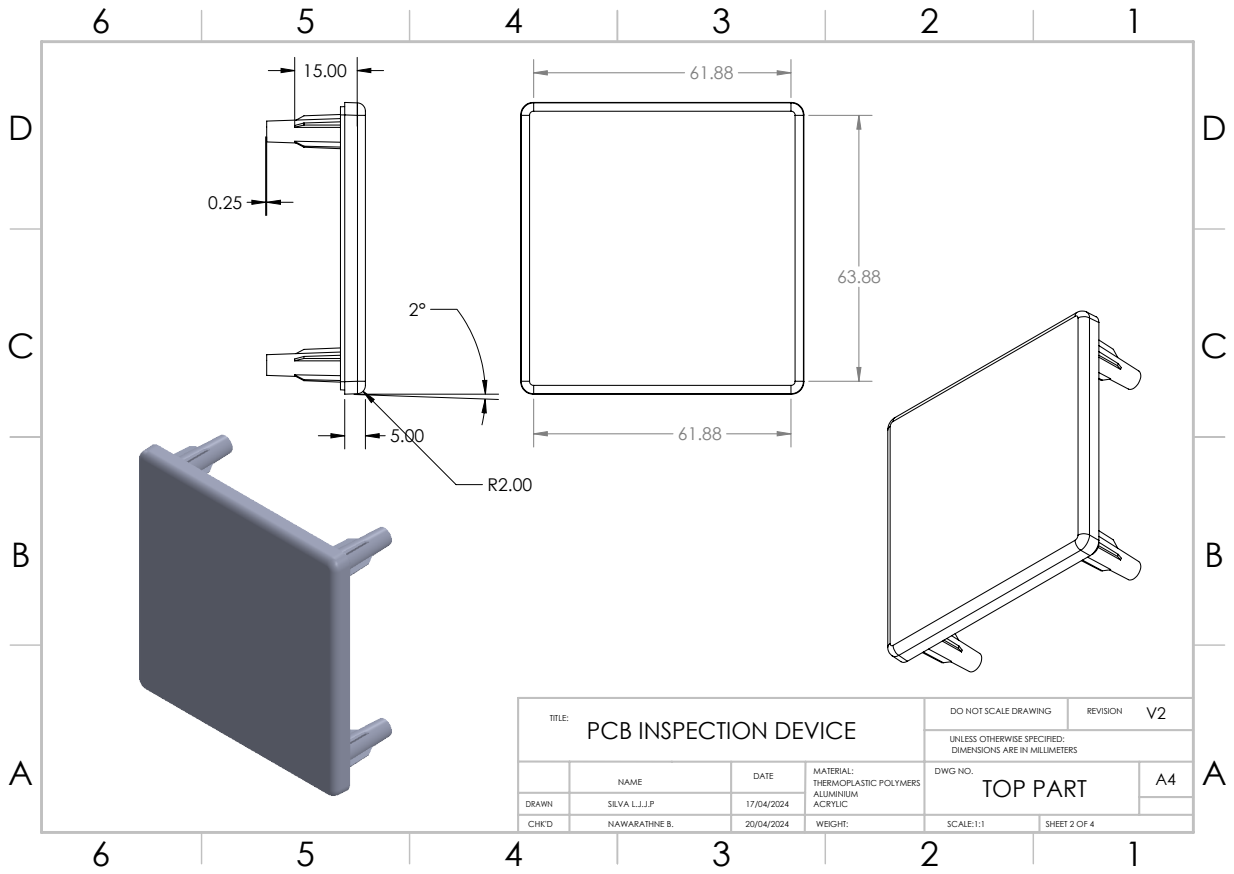
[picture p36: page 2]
THERMOPLASTIC POLYMERS; DO NOT SCALE DRAWING; REVISION TITLE:

PCB INSPECTION DEVICE

UNLESS OTHERWISE SPECIFIED:
DIMENSIONS ARE IN MILLIMETERS
DWG NO.

TOP PART SILVA L.J.J.P
NAME

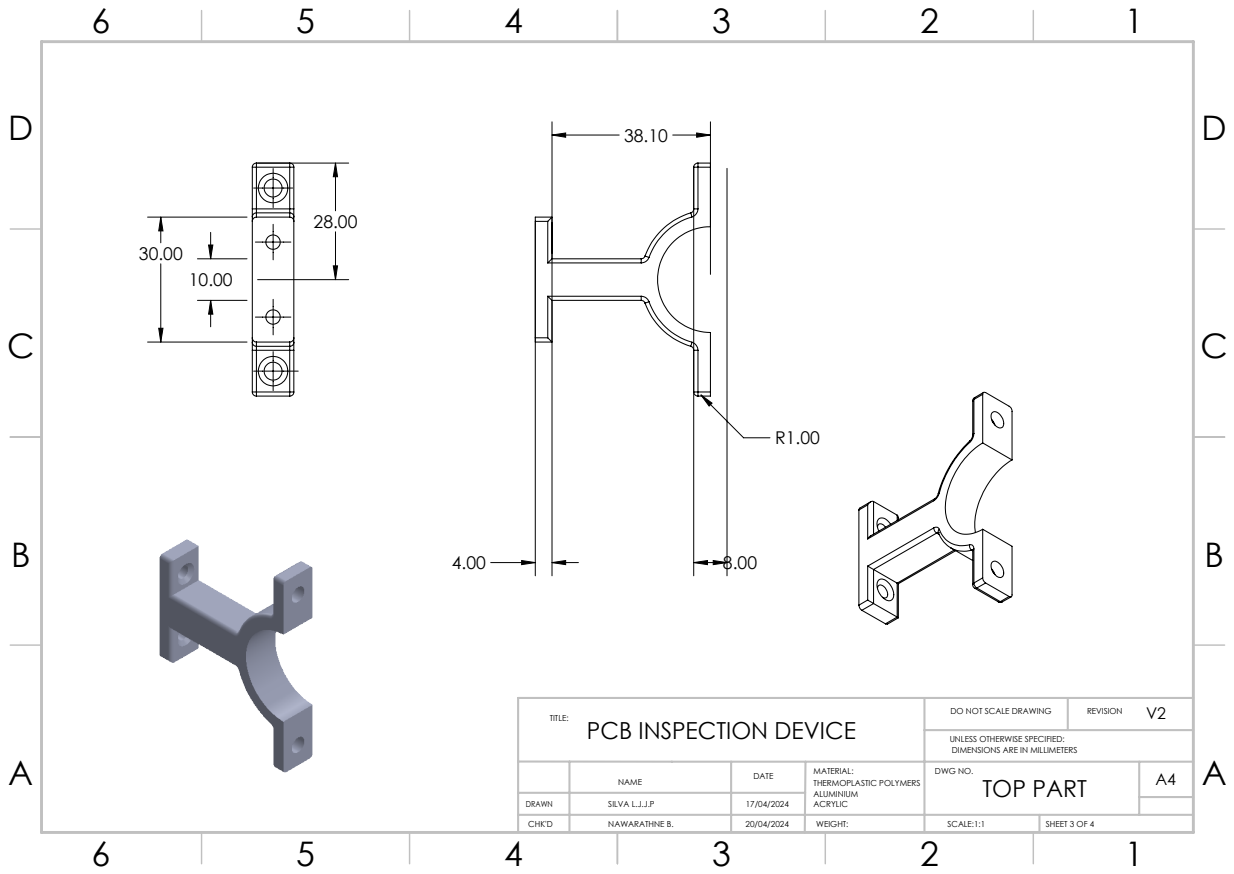
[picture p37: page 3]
THERMOPLASTIC POLYMERS; DO NOT SCALE DRAWING; REVISION TITLE:

PCB INSPECTION DEVICE

UNLESS OTHERWISE SPECIFIED:
DIMENSIONS ARE IN MILLIMETERS
DWG NO.

TOP PART SILVA L.J.J.P
NAME

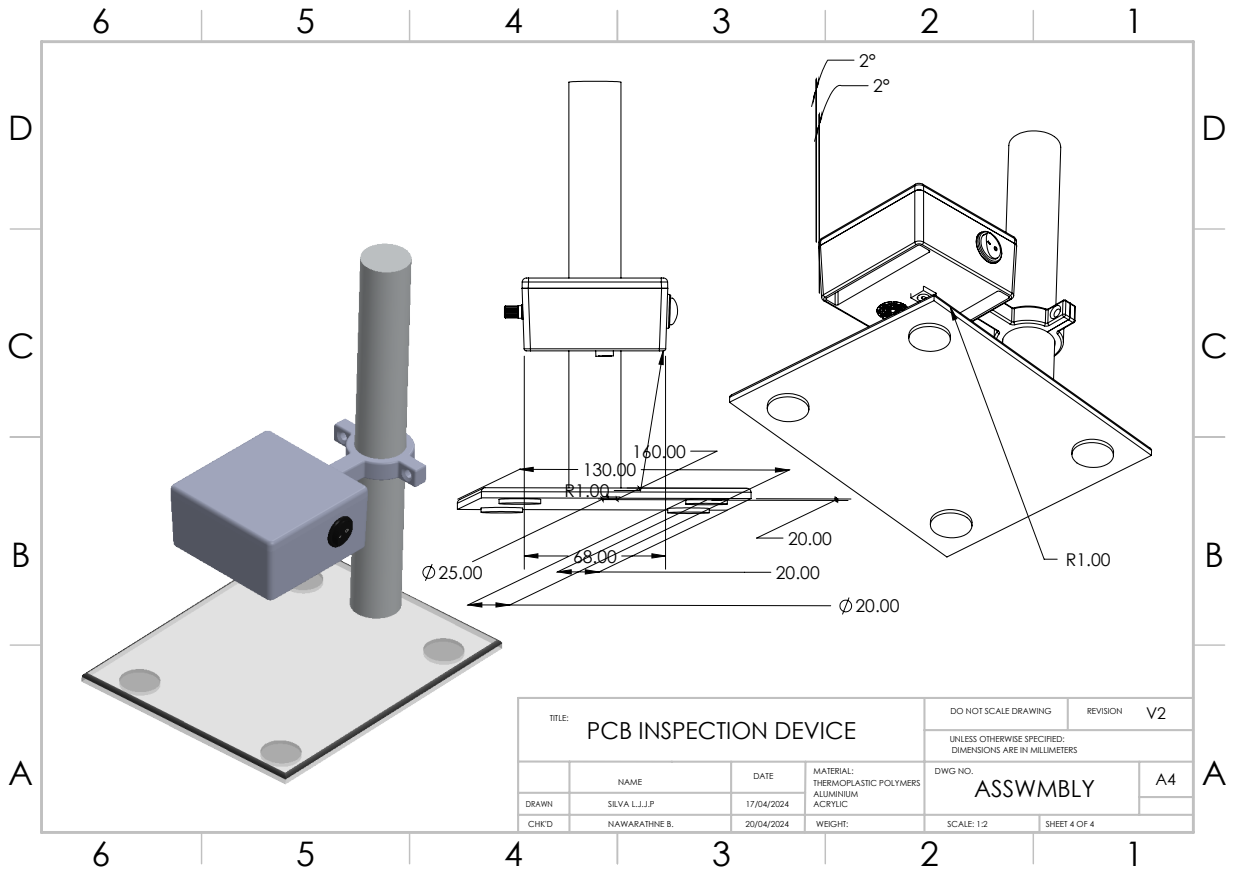
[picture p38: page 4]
THERMOPLASTIC POLYMERS; DO NOT SCALE DRAWING; REVISION TITLE:; SCALE: 1:2; SHEET 4 OF 4; ASSWMBLY SILVA L.J.J.P

PCB INSPECTION DEVICE

UNLESS OTHERWISE SPECIFIED:
DIMENSIONS ARE IN MILLIMETERS
DWG NO.

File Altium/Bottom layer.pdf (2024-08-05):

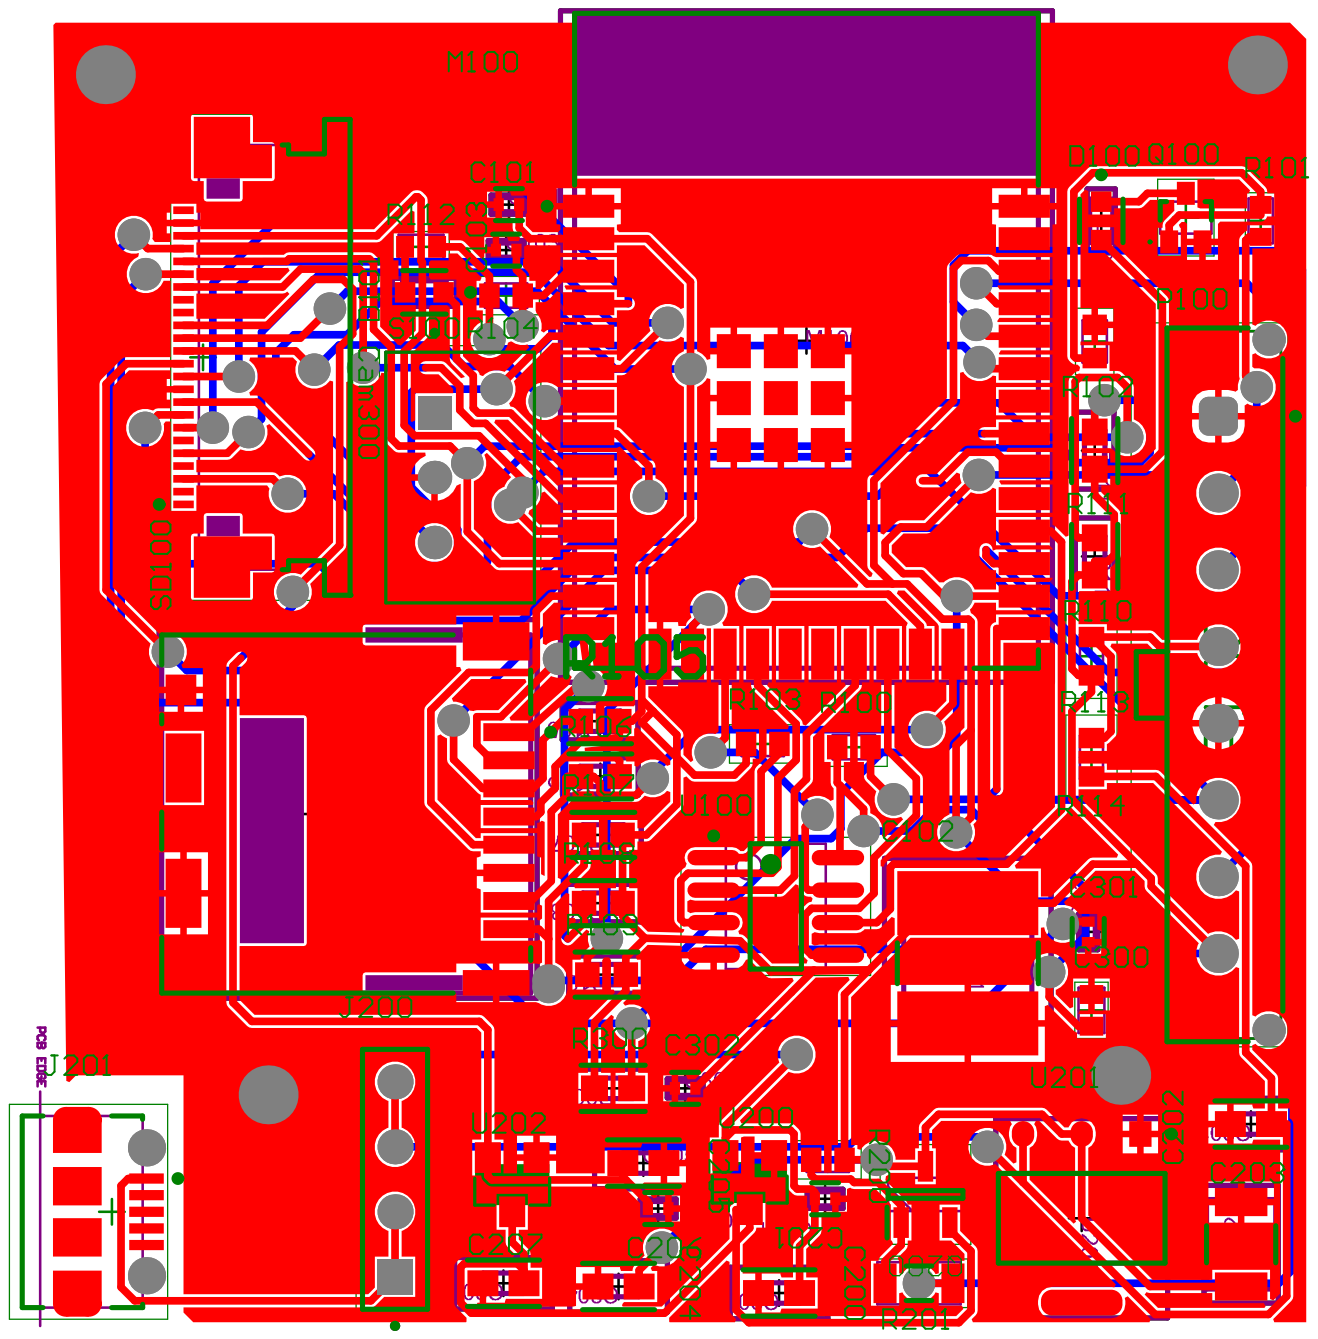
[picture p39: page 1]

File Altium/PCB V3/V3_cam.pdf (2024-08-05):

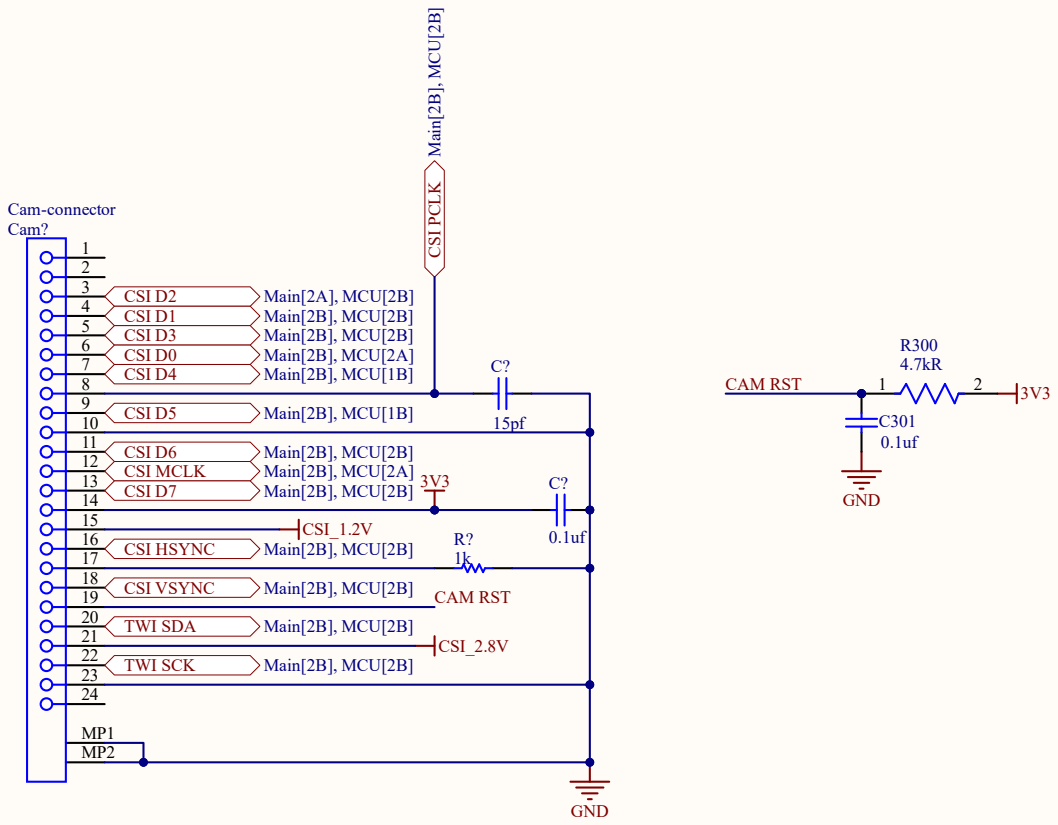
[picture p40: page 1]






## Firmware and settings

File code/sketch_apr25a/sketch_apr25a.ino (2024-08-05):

#include <WebServer.h>
#include <WiFi.h>
#include <esp32cam.h>
 
const char* WIFI_SSID = "Redmi 12";
const char* WIFI_PASS = "12341234";
 
WebServer server(80);
 
 
static auto loRes = esp32cam::Resolution::find(320, 240);
static auto midRes = esp32cam::Resolution::find(350, 530);
static auto hiRes = esp32cam::Resolution::find(800, 600);
void serveJpg()
{
  auto frame = esp32cam::capture();
  if (frame == nullptr) {
    Serial.println("CAPTURE FAIL");
    server.send(503, "", "");
    return;
  }
  Serial.printf("CAPTURE OK %dx%d %db\n", frame->getWidth(), frame->getHeight(),
                static_cast<int>(frame->size()));
 
  server.setContentLength(frame->size());
  server.send(200, "image/jpeg");
  WiFiClient client = server.client();
  frame->writeTo(client);
}
 
void handleJpgLo()
{
  if (!esp32cam::Camera.changeResolution(loRes)) {
    Serial.println("SET-LO-RES FAIL");
  }
  serveJpg();
}
 
void handleJpgHi()
{
  if (!esp32cam::Camera.changeResolution(hiRes)) {
    Serial.println("SET-HI-RES FAIL");
  }
  serveJpg();
}
 
void handleJpgMid()
{
  if (!esp32cam::Camera.changeResolution(midRes)) {
    Serial.println("SET-MID-RES FAIL");
  }
  serveJpg();
}
 
 
void  setup(){
  Serial.begin(115200);
  Serial.println();
  {
    using namespace esp32cam;
    Config cfg;
    cfg.setPins(pins::AiThinker);
    cfg.setResolution(hiRes);
    cfg.setBufferCount(2);
    cfg.setJpeg(80);
 
    bool ok = Camera.begin(cfg);
    Serial.println(ok ? "CAMERA OK" : "CAMERA FAIL");
  }
  WiFi.persistent(false);
  WiFi.mode(WIFI_STA);
  WiFi.begin(WIFI_SSID, WIFI_PASS);
  while (WiFi.status() != WL_CONNECTED) {
    delay(500);
  }
  Serial.print("http://");
  Serial.println(WiFi.localIP());
  Serial.println("  /cam-lo.jpg");
  Serial.println("  /cam-hi.jpg");
  Serial.println("  /cam-mid.jpg");
 
  server.on("/cam-lo.jpg", handleJpgLo);
  server.on("/cam-hi.jpg", handleJpgHi);
  server.on("/cam-mid.jpg", handleJpgMid);
 
  server.begin();
}
 
void loop()
{
  server.handleClient();
}

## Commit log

2024-08-05 altium file added
    [ESP32-Cam.SchDoc, MCU.SchDoc, Main.SchDoc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]
2024-08-05 Code and model
    [results.csv]
2025-02-04 PCB , Enclosure, Schematic images Uploaded
2025-02-04 Added v2 enclosure images
